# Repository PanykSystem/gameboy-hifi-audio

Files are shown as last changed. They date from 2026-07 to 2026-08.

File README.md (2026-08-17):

# GameBoy HiFi Audio

A Bluetooth audio upgrade for the Game Boy Advance. It removes the console's
stock audio amp and replaces the whole audio back end with an ESP32 and an
ES8388 codec. The mod streams game audio to Bluetooth headphones and speakers,
and it also drives the GBA's built-in speaker and wired headphone jack itself,
with onboard EQ, volume, and sound effects.

<p align="center">
  <a href="https://youtu.be/aRh9ZIPrqOQ">
    Watch: I Fixed the GBA's Audio
  </a>
  <br>
  <sub>What the mod does, start to finish</sub>
</p>

<p align="center">
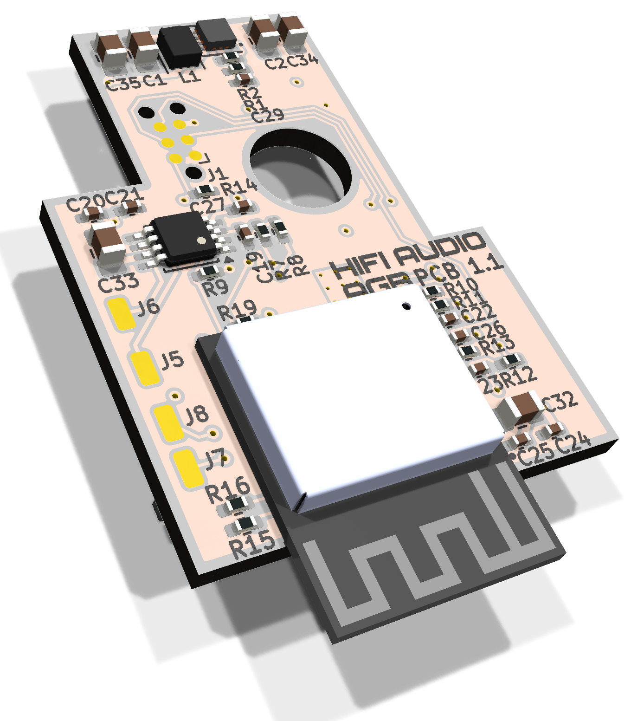
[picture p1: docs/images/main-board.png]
GameBoy HiFi AGB main board
  
  &nbsp;&nbsp;
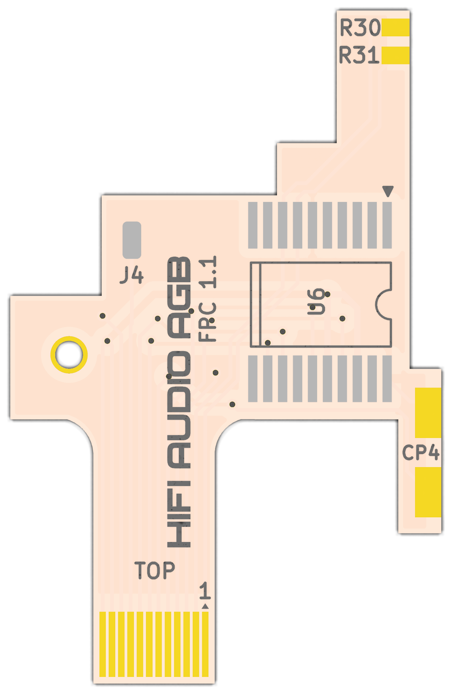
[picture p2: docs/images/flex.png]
GameBoy HiFi AGB flex
  
  <br>
  <sub>AGB main board (left) and flex (right)</sub>
</p>

What you get:

- Bluetooth (A2DP) output to any standard headphones or speaker.
- Wired headphones and the internal speaker, driven by the onboard codec.
- EQ, volume, and sound-effect cues, tunable from a phone or laptop over
  Bluetooth (no app install, it runs in the browser).
- A battery-saver mode that puts the radio and CPU to sleep and passes audio
  through the codec in analog, for long unplugged sessions.
- Firmware updates over Bluetooth.

<p align="center">
  The web config page: live spectrum and equalizer, tuned in the browser over Bluetooth
  <br>
  <sub>The browser config page: a live spectrum and per-output EQ, tuned over Bluetooth with no app to install</sub>
</p>

Prebuilt, pre-assembled kits are coming soon at
[cajunpanda.com](https://cajunpanda.com/shop/gameboy-hifi-audio), for anyone who would
rather not source the parts and solder it themselves. Kits ship pre-flashed and update
over Bluetooth, so they need no programming cable. The listing also has an A/B recording
of the mod with its filters off and on, and an optional speaker.

Questions, build photos, and troubleshooting happen on the
[Discord](https://discord.gg/6BNetnK6kC).

This repository currently holds the board for the original Game Boy Advance
(AGB). The firmware is shared across models. Boards for other Game Boy models
will be added under `hardware/` as they are designed.

## Pick your path

This project has three kinds of reader. Start with the doc that matches you.

- **You have a GameBoy HiFi board, or one already in your GBA.**
  [docs/AGB-INSTALL.md](docs/AGB-INSTALL.md) fits the board into a Game Boy Advance, and
  [docs/MANUAL.md](docs/MANUAL.md) covers using it: pairing, the control button,
  the modes, the web config page, and troubleshooting.

- **You want to build the boards yourself.**
  Read [docs/HARDWARE.md](docs/HARDWARE.md): the bill of materials, the KiCad
  boards, fabrication, and assembly. It links on to the install guide once the
  boards are ready.

- **You want to change the firmware.**
  Read [docs/FIRMWARE.md](docs/FIRMWARE.md): the toolchain, build and flash,
  the architecture, the config options, and how the control surfaces work.

## Repository layout

```
firmware/        ESP-IDF firmware (PlatformIO project), shared across boards
hardware/agb/    KiCad projects for the AGB main board and flex (schematic carries the BOM)
web/             Web Bluetooth config page (hosted on GitHub Pages)
tools/           make_clip.py (clip authoring), bringup.py (bench current<->boot correlation)
docs/            the guides above
```

## License

- Firmware and other source code: MIT, see [LICENSE](LICENSE).
- Hardware (schematics, board layouts, footprints): CERN-OHL-P v2, see
  [hardware/LICENSE](hardware/LICENSE).
- Documentation: CC BY 4.0, see [docs/LICENSE](docs/LICENSE).

You can build, modify, sell, and redistribute all of it, including in your own
products, as long as you keep the attribution and the license notices.

## A note on the trademark

Game Boy and Game Boy Advance are trademarks of Nintendo. This is an
independent, unofficial project and is not affiliated with or endorsed by
Nintendo.

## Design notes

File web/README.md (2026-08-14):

# Web config page

A single-file Web Bluetooth control panel for the mod's BLE config server
(`firmware/src/ble_config.c`). It tunes the DSP settings (speaker and Bluetooth
volume, EQ, sound effects), sets the R-button hold timings, plays chimes and
clips, saves to the device, and updates the firmware over the air. It also
converts a dropped audio file to a startup clip in the browser and uploads it.
No app, no WiFi, just Chrome or Edge talking to the ESP32 over Bluetooth.

## Hosting (GitHub Pages)

`.github/workflows/pages.yml` deploys this folder to GitHub Pages on every push
to `main` that touches `web/`. One-time setup: repo Settings, Pages, Source =
GitHub Actions. The page is then served at `https://<user>.github.io/<repo>/`.

Web Bluetooth needs a secure context, which the Pages HTTPS provides. For local
work, serve over localhost (for example `python3 -m http.server` in this folder).
Opening the file directly does not expose `navigator.bluetooth`.

## Use

1. Power the mod. The BLE server advertises as "GameBoy HiFi Setup" with slow
   advertising to keep current low, so discovery can take a couple of seconds.
2. Open the page, click Connect, and pick "GameBoy HiFi Setup".
3. The controls fill in from the device and push live edits back. Save to device
   persists them. Changes made from the UART console show up here through
   notifications.

On Linux, Chrome needs the experimental web platform features flag.

## Firmware update

The Firmware update card pushes a new `firmware.bin` to the device over
Bluetooth. Drop the file, click Flash firmware, and keep the page open until the
device reboots into the new image (a minute or two; audio pauses). The transfer
uses windowed flow control with a host-side crc32 and on-device SHA-256
validation before the boot slot swaps. The dropped file is checked before any of
it is sent: it has to be an ESP32 app image, built from this project, and small
enough for the app slot, so the cable-only full-flash image or another product's
firmware is refused in the picker instead of partway through a transfer. The
device enforces the same project check itself when the transfer ends. Older firmware without the OTA
characteristics is detected, and the card disables itself.

The card shows the installed firmware version and slot from the device. The
version comes from `CONFIG_APP_PROJECT_VER` in `firmware/sdkconfig.defaults`.

## Wire format

The settings characteristic is a packed little-endian blob mirroring
`gbhifi_settings_t`. The exact layout is documented in both `web/index.html` and
`firmware/src/ble_config.c` (`SETTINGS_WIRE_LEN`); keep the two in lockstep. The
mode field is read-only status: entering Battery saver duty-cycles the radio to
sleep, so the page cannot reverse it. The R-button hold gesture owns the mode.

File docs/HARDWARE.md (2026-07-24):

# GameBoy HiFi Audio: Hardware Guide

This guide is for building the mod yourself: ordering the boards, sourcing
parts, assembling, and installing it in a Game Boy Advance. The KiCad projects
under `hardware/agb/` are the authoritative reference for the schematic, the
board layout, and the exact net and pin assignments. This document is the
overview.

This is an advanced modification. It requires removing a surface-mount chip from
the GBA mainboard, fine-pitch soldering, and reflow or hot-air work on a QFN
part. If you are not comfortable with that, have it done by someone who is.

## What is on the boards

There are two boards for the AGB:

- **Main board** (`hardware/agb/agb-hifi-audio-pcb`): the ESP32 module, the
  audio codec, the power supply, and the speaker amplifier.
- **Flex** (`hardware/agb/agb-hifi-audio-fpc`): a flexible circuit that solders
  to the GBA's audio-amp footprint and carries power, ground, the audio taps,
  and the control-button signal back to the main board. It folds over once
  during installation.

<p align="center">
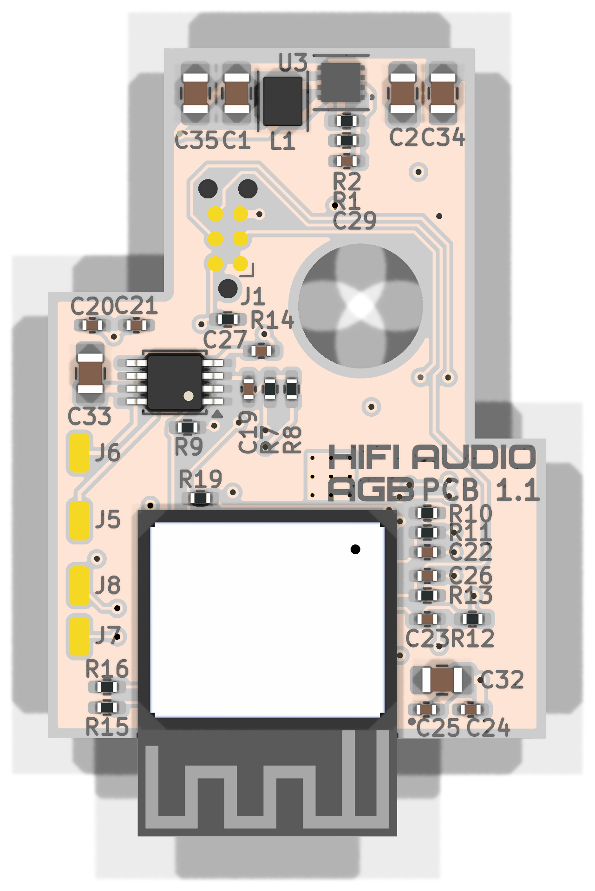
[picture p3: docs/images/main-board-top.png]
AGB main board, top
  
  &nbsp;&nbsp;
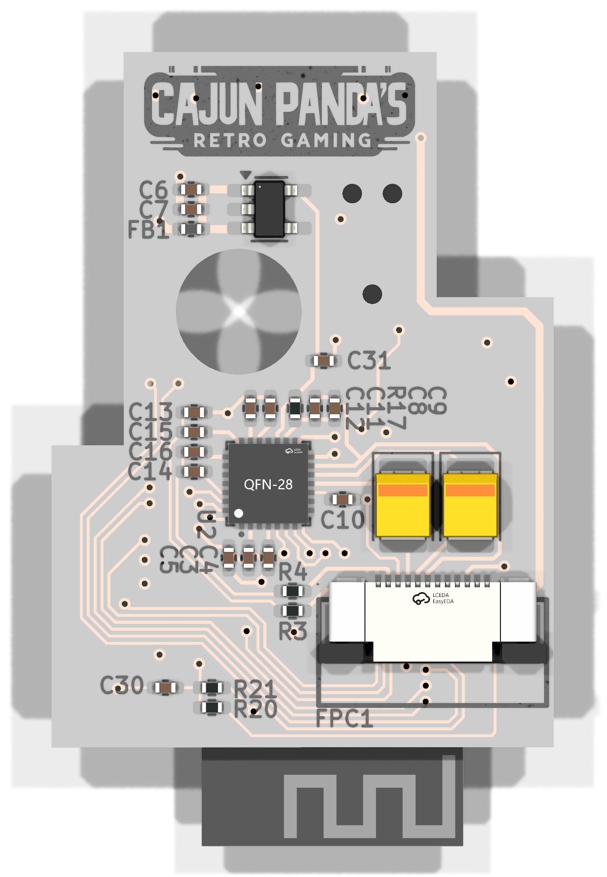
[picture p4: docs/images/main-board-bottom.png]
AGB main board, bottom
  
  <br>
  <sub>Main board, top (left) and bottom (right)</sub>
</p>

## Key parts

The bill of materials lives in the KiCad schematic itself (the source of truth),
where each symbol carries its manufacturer, LCSC, and DigiKey part numbers. Export
it from the [main-board schematic](../hardware/agb/agb-hifi-audio-pcb/). The main
active parts are:

| Ref  | Part | Function |
| ---- | --- | --- |
| U1 | ESP32-PICO-MINI-02-N8R2 | MCU, Bluetooth radio, 8 MB flash |
| U2 | ES8388 | Stereo audio codec: ADC, DAC, headphone amp, analog bypass |
| U3 | TPS61021A | Boost converter, battery to 3.3 V |
| U4 | PAM8302A | Mono Class-D amplifier for the internal speaker |
| U5 | LP5907MFX-3.0 | Low-noise LDO for the codec's analog supply |
| FPC1 | AFC07-S12ECA-00 | 12-pin flat-flex connector for the flex |

The ES8388 is a QFN-28 and is not hand-solderable in the usual sense. Plan on a
stencil and reflow, or hot air. The ESP32 module needs the same treatment: its
pads sit under the module's edge rather than as exposed castellations, so an iron
cannot reach them all. Its pitch is coarser than the codec's, so it is the more
forgiving of the two, but it is still a reflow or hot-air part.

FPC1 is a JLCPCB-stocked part (LCSC C262585). It replaced the Hirose
FH12A-12S-0.5SH, which mates the same flex but uses a different fitting-nail
land pattern, so the Hirose only fits board revisions before 1.1.

### Full bill of materials

Passives are listed by value; the schematic carries the exact manufacturer,
LCSC, and DigiKey part numbers for every line. 26 lines, 60 pieces.

| Ref(s) | Qty | Value / part | Package |
| --- | --- | --- | --- |
| C1, C2, C32–C35 | 6 | 22 µF 25 V | 0805 |
| C3, C6, C8, C10, C11, C20, C24 | 7 | 10 µF | 0402 |
| C4, C7, C9, C21, C25, C26, C30 | 7 | 100 nF | 0402 |
| C5, C15, C16, C19, C27, C31 | 6 | 1 µF | 0402 |
| C12 | 1 | 4.7 µF | 0402 |
| C13, C14 | 2 | 10 nF C0G | 0402 |
| C17, C18 | 2 | 220 µF 6.3 V (tantalum) | EIA-3528 |
| C22, C23 | 2 | 10 nF | 0402 |
| C29 | 1 | 10 pF | 0402 |
| R1 | 1 | 316 kΩ | 0402 |
| R2, R9, R20, R21 | 4 | 100 kΩ | 0402 |
| R3, R4 | 2 | 2.2 kΩ | 0402 |
| R7, R8 | 2 | 15 kΩ | 0402 |
| R10, R13, R14 | 3 | 10 kΩ | 0402 |
| R11, R12 | 2 | 1 kΩ | 0402 |
| R15, R16 | 2 | 4.7 kΩ | 0402 |
| R17 | 1 | 10 Ω | 0402 |
| R19 | 1 | 33 Ω | 0402 |
| L1 | 1 | 0.47 µH (power inductor) | 2.5 × 2.0 mm |
| FB1 | 1 | 600 Ω @ 100 MHz (ferrite bead) | 0402 |
| FPC1 | 1 | AFC07-S12ECA-00 | 12-pin FFC |
| U1 | 1 | ESP32-PICO-MINI-02-N8R2 | SMD module |
| U2 | 1 | ES8388 | QFN-28 (4 × 4 mm) |
| U3 | 1 | TPS61021A | WSON-8 (2 × 2 mm) |
| U4 | 1 | PAM8302A | MSOP-8 |
| U5 | 1 | LP5907MFX-3.0 | SOT-23-5 |

## Ordering the boards

Open the KiCad project (KiCad 10 or newer) and export fabrication data:

1. Run the design rule check and the electrical rule check first.
2. Plot Gerbers and drill files for the main board, and again for the flex.
3. Export the position (centroid) file if you are using an assembly service.

The flex needs special fabrication settings: it is a two-layer polyimide flex
with a stiffener under the connector fingers, and a few intentional edge-plated
lands. Those requirements are written into the flex board as fabrication notes
on the documentation layer, so they travel with the Gerbers. Read them before
you order, and tell the fab house it is a flex, not a rigid board.

JLCPCB and PCBWay both make these. For the main board, their assembly services
can place most of the parts, which saves you the QFN reflow. The JLCPCB order-form
settings used for these boards (flex material, ENIG, coverlay, stiffener, and the
rest) are recorded in [JLCPCB-FAB-ORDER.md](JLCPCB-FAB-ORDER.md) so reorders stay
consistent.

## Power

The GBA's switched battery rail (about 2.4 V to 3.2 V) feeds the TPS61021A
boost converter, which produces 3.3 V for the ESP32, the codec's digital side,
and the speaker amp.

The codec's analog supply (AVDD, and HPVDD behind R17) is its own domain: the
3.3 V rail passes through the ferrite (FB1) into U5, an LP5907MFX-3.0 low-noise
LDO (~82 dB PSRR at 1 kHz), which regulates a quiet 3.0 V for the codec's analog
stages. It isolates the codec's DAC, mixer, and headphone amp from the boost
rail, which the Bluetooth radio's wake-up bursts modulate. Bulk caps are spread
across the rail (boost output, boost input, ESP32, speaker amp) for brown-out
margin at low battery.

## The audio source

The GBA CPU does not output a line-level analog signal. Its sound pins (S01 and
S02) are a PWM bitstream. The reconstruction that turned that into analog used
to live inside the amp chip you are removing, so the mod includes its own
reconstruction low-pass filter at the tap. The filtered signal feeds the codec's
line inputs. The codec's input range suits this signal directly, so there is no
preamp.

## Installing the mod

Once the boards are assembled, see [AGB-INSTALL.md](AGB-INSTALL.md) to fit the mod into
a Game Boy Advance: removing the stock parts, attaching the flex, wiring the
speaker, and the first firmware flash.

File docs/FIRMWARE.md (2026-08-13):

# GameBoy HiFi Audio: Firmware Guide

This guide is for building, flashing, and modifying the firmware. The firmware
is shared across all board models.

## Toolchain

The firmware is an ESP-IDF project built through PlatformIO, not through
`idf.py`. You need:

- PlatformIO (the `pio` CLI, or the VS Code extension).
- A Tag-Connect TC2030 serial cable for the first cabled flash. The
  [TC2030-NL-FTDI-C232HD](https://www.tag-connect.com/product/tc2030-nl-ftdi-c232hd-ddhsp-0-dtr-usb-to-tc2030-no-legs-serial-cable)
  carries DTR for auto-reset into the bootloader. Later updates go over Bluetooth.

PlatformIO downloads the ESP-IDF framework and the managed components on the
first build. `firmware/sdkconfig.defaults` is the source of truth for the IDF
configuration; the generated `sdkconfig.prod` is not checked in and is
recreated from the defaults.

## Build, flash, monitor

All firmware commands run from inside `firmware/`:

```sh
cd firmware
pio run                          # build
pio run -t upload                # flash over serial
pio run -t upload -t monitor     # flash and open the serial monitor
pio run -t menuconfig            # IDF menuconfig (edits the generated sdkconfig)
pio device monitor               # serial monitor only (115200 8N1)
```

The build output is `.pio/build/prod/firmware.bin`.

### Recommended: benchmux for iterating

For a build-flash-watch loop, [benchmux](https://github.com/cajunpanda/benchmux) is more
convenient than the raw `pio` commands. It owns the serial port and tees output to a shared
logfile, so it flashes without stopping the monitor, the boot log for the new firmware
streams straight into the log you are already watching, and you can follow that log from any
terminal. It also flashes over BLE. Install it per its README, then from `firmware/`:

```sh
serial_proxy.py monitor --port FTDI &    # own the port, stream to /tmp/serial_proxy.log
serial_proxy.py tail                     # follow the log (from any terminal)
serial_proxy.py flash --env prod         # build + upload without stopping the monitor
serial_proxy.py flash --env prod --fs    # also flash the LittleFS clip image
serial_proxy.py send get                 # inject a console command through the monitor
```

`--fs` flashes the LittleFS clip image that a plain upload skips (see "Partitions and the
clip image"), so a `firmware/data/` change needs no separate esptool step. The commands run
once and exit with a status code, which also makes benchmux a good fit for driving the board
from an editor task or an AI coding agent.

If you change `sdkconfig.defaults`, delete `sdkconfig.prod` to force it to
regenerate. Adding a new `CONFIG_*` symbol in `Kconfig.projbuild` also needs
that delete plus a rebuild, otherwise the build reports the symbol as
undeclared.

`pio run -t upload` flashes only the app. It does not write the LittleFS clip
image, so a change under `firmware/data/` needs a separate filesystem flash (see
"Partitions and the clip image" below).

## Configuration

Project options live in `firmware/src/Kconfig.projbuild` under the
"GameBoy HiFi Audio" menu. Reach them with `pio run -t menuconfig`. The groups:

- **Timeouts and timing**: standby and reconnect timing, the silence detector,
  the R-button hold thresholds, debounce, pairing and wake-hold times, and the
  factory-reset hold.
- **BLE GATT config server**: enables the Web Bluetooth control surface.
- **Speaker DSP defaults**: first-boot seed values for volume, the three EQ
  profiles (speaker, headphone, Bluetooth), and the sound cues. These are only
  the initial seeds; live values persist in NVS and are tuned at runtime.
- **Operating modes**: the default mode at boot, and what happens on a wired
  headphone unplug while in Battery saver.
- Two debug toggles: per-second ADC peak logging, and a one-shot waveform dump
  over UART.

## Partitions and the clip image

`firmware/partitions.csv` defines an 8 MB layout with two OTA app slots (so the
firmware can update itself over Bluetooth), an NVS area for settings and
Bluetooth bonds, and a LittleFS `storage` partition for sound clips.

`pio run -t upload` flashes only the app. It does not flash the LittleFS clip
image, so a plain flash leaves whatever clips were already on the board. The
build bakes `firmware/data/` into a `storage.bin` image (the `src/CMakeLists.txt`
`littlefs_create_partition_image(... FLASH_IN_PROJECT)` line owns the exact
fs-size / block-size / name-max the firmware mounts with). To (re)load the clips,
build and write that image to the `storage` partition offset:

```sh
pio run                                              # bakes .pio/build/prod/storage.bin
esptool.py write_flash 0x420000 .pio/build/prod/storage.bin
```

The `storage` offset (`0x420000`) comes from `partitions.csv`; the generated
`flasher_args.json` lists it too.

The first flash on a fresh board must be a full cabled flash: bootloader,
partition table, app into the first slot, an erased otadata, and the clip image.
After that, updates can go over Bluetooth.

The clips themselves are in the GSFX format. Use `tools/make_clip.py` to author
them: `from-wav` converts a 16-bit WAV to a clip (downmix + optional resample),
or `gen-startup` generates a synth test cue.

The boot chime plays over a muted passthrough (see "Init order"). Which clip it
uses comes from the `startup_mode` setting, whose values are `startup_mode_t` in
`settings.h`:

| mode | clip | notes |
| --- | --- | --- |
| `STARTUP_MODERN` | `startup-modern.gsfx` | the Switch/NSO version, the default |
| `STARTUP_ORIGINAL` | `startup-original.gsfx` | the full original GBA chime |
| `STARTUP_CUSTOM` | `startup-custom.gsfx` | ships with a default; replaced by a web-UI upload |
| `STARTUP_OFF` | none | no clip; the live GBA chime plays through |

`STARTUP_OFF` is not `STARTUP_ORIGINAL`. The codec and amp are still coming up
during the GBA's first ~0.9 s, so the passthrough chime is truncated. That is why
the mod voices its own clip.

All three clips ship in the filesystem image. To change one, author a new
`firmware/data/startup-*.gsfx` and reflash the image (see "Partitions and the
clip image").

The web config page can also replace `startup-custom.gsfx` over BLE. It converts
a dropped audio file to GSFX in the browser, then streams it over the same
OTACTL/OTADATA characteristics a firmware update uses (opcodes `CLIP_BEGIN` /
`CLIP_END`). The device writes to a temp file and renames it into place only once
size, CRC32 and the GSFX header check out, so a dropped link leaves the previous
clip intact. A filesystem reflash restores the bundled default.

## Source layout

```
firmware/src/
  main.c            app_main and the boot/init order
  pinmap.h          every PIN_* macro (the single source of truth for GPIOs)
  es8388.{h,c}      codec driver over I2C: power-up, mode, routing, volume
  i2s_codec.{h,c}   full-duplex I2S master to the codec (MCLK from the ESP32)
  audio_pipeline.{h,c}  ADC capture, int16 conversion, DSP, BT stream, DAC fan-out
  dsp.{h,c}         EQ, volume, and cue mixing for the speaker and BT paths
  settings.{h,c}    runtime-tunable parameters, NVS-backed, the control seam
  sfx.{h,c}         cue player: synth cues and clips streamed from LittleFS
  fs.{h,c}          LittleFS mount for the clip store
  console.{h,c}     UART REPL control surface
  ble_config.{h,c}  BLE GATT config server (drives the web page)
  bt_a2d.{h,c}      Bluedroid wrapper: connect, pair, media, bonds, events
  buttons.{h,c}     debounced ISR for the control button and HP-detect
  harness.{h,c}     install diagnostics for the four signals crossing to the GBA
  app_sm.{h,c}      the state machine, speaker-amp gating, and sleep policy
```

## Architecture

### Audio path

The GBA sound pins (S01/S02) are a PWM bitstream. A reconstruction low-pass
filter on the board turns that into analog, which feeds the codec line inputs.
From there:

```
codec ADC -> ESP32 (I2S RX) -> int16 stereo -> DSP -> split:
  Bluetooth:  stream buffer -> A2DP SBC encoder -> radio
  Local:      codec DAC -> headphone amp (jack) and line out -> speaker amp
```

The pipeline is fixed at 44.1 kHz interleaved stereo, 16-bit. The IDF A2DP
source endpoint hard-codes that SBC format and rejects attempts to change it, so
the sample rate, channel count, and bit depth across the codec, the I2S bus, and
the pipeline all exist to feed that fixed sink. Do not change one without the
others.

### Clocking

The ESP32 is the I2S master. It generates MCLK (from the APLL on GPIO0), BCLK,
and LRCK, and the codec is the slave. One clock domain serves both directions,
so there is no asynchronous resampling.

### Init order

`app_main` is ordered to get **audio out as fast as possible** and to keep the
Bluetooth radio off the Game Boy power-on chime. The mod boots on the GBA's
switched rail, so every power-cycle re-runs this and the chime is the first thing
the user hears.

The sequence: log the wake cause and gate a button wake, boot-mute the speaker
amp, init NVS, bring up the I2S clocks and then the codec over I2C. As soon as the
codec is configured, `app_sm_speaker_early_on()` samples HP-detect and unmutes the
speaker amp (only if no headphones are plugged) — well before the state machine
would otherwise. Then the DSP subsystem comes up: `app_sm_prime_volume()` seeds
the speaker volume from the wheel *before* `dsp_init()` reads it (so a wheel-down
user doesn't get a default-volume blare), and the local EQ profile is seeded from
the sampled HP state. The startup chime is then triggered — `dsp_begin_intro()`
mutes the live passthrough while `sfx_trigger_clip("startup")` plays the mod's own
clean, complete chime (so it isn't doubled with the truncated live GBA chime the
codec misses during boot); this is gated so a future setting can disable it and
let the GBA's own chime through. The audio pipeline and buttons start, and the
pending OTA image is confirmed good.

Only then comes Bluetooth, deliberately last among the heavy loads: `app_main`
waits until `CONFIG_GBHIFI_BT_START_DELAY_MS` after power-on **and** until the
startup chime has fully drained (`sfx_cue_active()`, capped so a wedged cue can't
block BT), parks the speaker amp (`app_sm_amp_radio_quiet()`) across the radio
window, then runs `bt_a2d_init()` (controller + radio) and the BLE config server.
This serialization exists because the radio bring-up is the largest, fastest
current step of the whole boot and on a low battery it can sag the boost rail
below the brownout threshold. Three more pieces of that guard live in firmware:

- `CONFIG_ESP_PHY_RF_CAL_NONE=y` (sdkconfig.defaults) — skips the boot-time
  partial RF calibration TX bursts and runs from NVS-stored cal data. Caveat:
  the first boot after an NVS erase runs a *full* cal (bigger spike), where the
  loop breaker below is the safety net.
- **BR/EDR TX capped at -3 dBm right after controller enable** (bt_a2d.c), so
  inquiry/page bursts never run at the +9 dBm default; the CONNECTED handler
  re-asserts the same level per link.
- **Brownout loop breaker** (main.c): an RTC-noinit magic word is armed around
  the radio bring-up and cleared on success. A boot that starts with reset
  reason BROWNOUT while armed knows the radio killed it: the first strike
  retries after a 2 s settle, two consecutive strikes skip BT for that boot and
  come up LOCAL_ONLY (chime + local audio always play instead of a reboot
  loop). A real power cycle scrambles RTC noinit and re-arms BT. All public
  `bt_a2d_*` calls no-op safely on a BT-skipped boot.

This sequence cold-boots cleanly down to a 2.0 V rail, below any usable 2xAA
level. Finally the factory-reset check, the state machine, and the console start.
The order matters; read the comments in `main.c` before reordering anything.

There is no codec read-back verify pass: the production PCB's series-R + short
MCLK routing keep the I2C config writes clean, so `es8388_init()` alone is enough.

### State machine

`app_sm.c` is the only place that owns device state. Button events, Bluetooth
events, audio silence edges, and timers all fold into one FreeRTOS queue drained
by a single task, so there are no cross-task races on the state. It also owns
the speaker-amp mute policy and the sleep policy.

The audio pipeline and the Bluetooth wrapper are isolated from each other and
from the state machine. They publish events through callbacks, and the state
machine is the only subscriber. Keep that boundary: do not add direct calls
between modules.

### Real-time threading

The real-time audio tasks are pinned to core 1, off the Bluetooth controller
core, or A2DP streaming gets garbled when the controller preempts a shared core.
Tickless idle is off for the same timing reason. There is no per-sample `sinf`
or `expf` in the audio task; the DSP uses lookup tables.

## Settings and control surfaces

`settings.c` is the single source of truth for runtime-tunable parameters
(volumes, the EQ profiles, the cues, the mode preferences, the hold times). It
is thread-safe, NVS-backed, and versioned, with a generation counter so the DSP
recomputes coefficients only when something changes.

Control surfaces only ever call the `settings_*` and `sfx_*` API. They never
touch the audio path. There are two:

- **The UART console** (`console.c`): a REPL for bring-up and tuning.
- **The BLE config server** (`ble_config.c`): the same API exposed over
  Bluetooth for the web page.

### Console commands

```
vol <0-100>          speaker volume
volbt <0-100>        Bluetooth volume
eq on|off [b m t]    speaker EQ
eqhp on|off [b m t]  headphone EQ
eqbt on|off [b m t]  Bluetooth EQ
sfx on|off [level]   cue mixing
chime [name]         play a synth cue
play <name>          play a clip
bt connect|pair      drive BT like the button (page bonds / inquiry-pair)
mode a|b             set operating mode (a = bypass/battery, b = DSP)
unplug stay|b        behavior on HP unplug in Mode A
hold [c p m e]       R-button hold thresholds, ms
wheel on|off         VOL wheel drives volume
diag                 install check: VBAT / VOL / PAIR / HP
ls                   list the clip store
save                 persist settings to NVS
get                  show current settings
```

There are also a few bench helpers (`out1`, `out2`, `outvol`, `codecmode`,
`hp`, `sleep`) for hardware bring-up.

## Install check

Four signals run from the mod board to the Game Boy through `FPC1` and the flex,
and `harness.c` classifies each one. The report goes to the boot log, the `diag`
console command, and the BLE `diag` characteristic that drives the web card.

| Signal | FPC1 pin | Open reads as | Why |
| --- | --- | --- | --- |
| VBAT | 11, 12 | ~280 mV vs 2000-3200 installed | the `R20`/`R21` divider is on-board but the rail it measures is not |
| VOL | 7 | raw ~16 vs a ~330 floor | the wheel is a VBAT-referenced divider, so its wiper cannot reach ground |
| PAIR | 9, then flex `J4` | stuck pressed | no pull-up exists on this net anywhere, so it floats LOW |
| HP | 8 | stuck plugged | `R10` pulls it up on-board, upstream of the connector |

Two consequences worth knowing:

- **PAIR floats.** The AGB CPU's keypad pull-up is what holds it HIGH, reached
  through the hand-soldered wire at flex `J4`. A bare board therefore reads the
  Connect/Pair button as permanently held. The boot-time factory reset is gated
  on the battery rail for exactly this reason: without it, every bench visit
  wiped a repaired unit's bonds.
- **HP cannot be judged alone.** "Headphones plugged" and "sense line open" are
  the same level. The report only calls it open once VBAT says the board is on
  bench power, where headphones are implausible.

An open VOL line is also ignored rather than obeyed, so a floating wire cannot
drag the volume to zero and hold it there.

## Web config page

`web/index.html` is a single static page that talks to the BLE config server
over Web Bluetooth. There is no build step and no backend. It is published to
GitHub Pages by `.github/workflows/pages.yml` on any push that touches `web/`.
Web Bluetooth needs a secure context, which the Pages HTTPS provides. The page
reads and writes the settings, uploads clips, and pushes firmware updates.

The System tab mirrors the UART REPL: it streams the device log and takes the
same console commands (`help`, `get`, `batt`, `nr`, ...), so you can watch and
poke a running board over BLE with no cable.

<p align="center">
  The System tab device console: live log and command input over BLE
  <br>
  <sub>The System tab's device console: the live log and the same commands as the wired console, over Bluetooth.</sub>
</p>

## OTA updates

The firmware can update itself over Bluetooth. The web page pushes a new
`firmware.bin` to the BLE OTA characteristics; the device writes it to the
inactive app slot, verifies it, swaps the boot slot, and reboots. If a fresh
image fails to finish booting, the bootloader rolls back to the previous slot.
The running image confirms itself good only after init completes without a
panic.

## Board targets

The build targets the ESP32-PICO-MINI-02-N8R2 module (8 MB flash) on the
production board. `pinmap.h` holds every GPIO assignment and is the single source
of truth for pins; the flash size and partition table are set in
`sdkconfig.defaults` and `partitions.csv`. There is one PlatformIO env, `prod`,
so the build output is always `.pio/build/prod/firmware.bin`.

To bring the firmware up on a different ESP32 module (for example a dev board on
the bench), add a PlatformIO env and adjust the GPIO values in `pinmap.h`, which
is the only file the pin map lives in.

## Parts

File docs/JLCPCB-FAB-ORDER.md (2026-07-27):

# JLCPCB Fab Order Settings

Recorded JLCPCB order configuration for the GameBoy HiFi boards, so reorders stay
consistent. The gerbers, BOM, and CPL come from the export in
[HARDWARE.md → Ordering the boards](HARDWARE.md#ordering-the-boards); this file
captures the fab-side options you pick in the JLCPCB order form after upload.

Most settings are board-agnostic (material, finish, stackup, coverlay, stiffener)
and carry across revisions. The **dimension** and **gerber file name** change per
revision — update those to match the package you are uploading.

## Flex — agb-hifi-audio-fpc

The flex is the fiddly one: a 2-layer polyimide flex with ENIG gold-finger
contacts, a white coverlay, and a polyimide stiffener under the connector lead.
The values below were captured from an order of this board.

### Board & material

| Setting | Value |
| --- | --- |
| Base Material | Flex |
| Layers | 2 |
| PCB Thickness | 0.11 mm |
| Substrate Type  | 25 µm dielectric thickness |
| Specify Stackup | No |
| Layer Sequence  | (default) |

### Copper & finish

| Setting | Value |
| --- | --- |
| Copper Type | Electro-deposited |
| Outer Copper Weight | 1/3 oz |
| Surface Finish | ENIG (gold thickness 1 U") |
| Gold Fingers | Yes |
| Gold Fingers bevel  | 0.3 mm |

### Coverlay & silkscreen

| Setting | Value |
| --- | --- |
| Coverlay Color | White |
| Coverlay Thickness | PI 12.5 µm / AD 15 µm |
| Silkscreen | Black |
| Silkscreen on Stiffener | No |

### Stiffener

| Setting | Value |
| --- | --- |
| Stiffener | Polyimide |
| Polyimide Thickness | 0.225 mm  |
| PI Stiffener Lift Tab | No |

The design does not call out a stiffener thickness — what it requires is a total
finished thickness of 0.30 ±0.05 mm at the fingers, so the tail seats in the ZIF.
Against a 0.11 mm flex body, JLCPCB's 0.225 mm polyimide lands at 0.335 mm, which
is inside that band. Another fab with a different set of stiffener thicknesses
picks whatever hits the same total. The stiffener area itself is the filled
rectangle on the `JLC_Stiffener_Bottom` layer, at the tip of the connector tail
on the bottom side.

### EMI shielding

| Setting | Value |
| --- | --- |
| EMI Shielding Film | Without |

## Main board — agb-hifi-audio-pcb

4-layer rigid FR-4, assembled (JLCPCB places most parts, saving the QFN reflow).
Settings not yet captured — fill in from the order form when the main board is
next ordered.

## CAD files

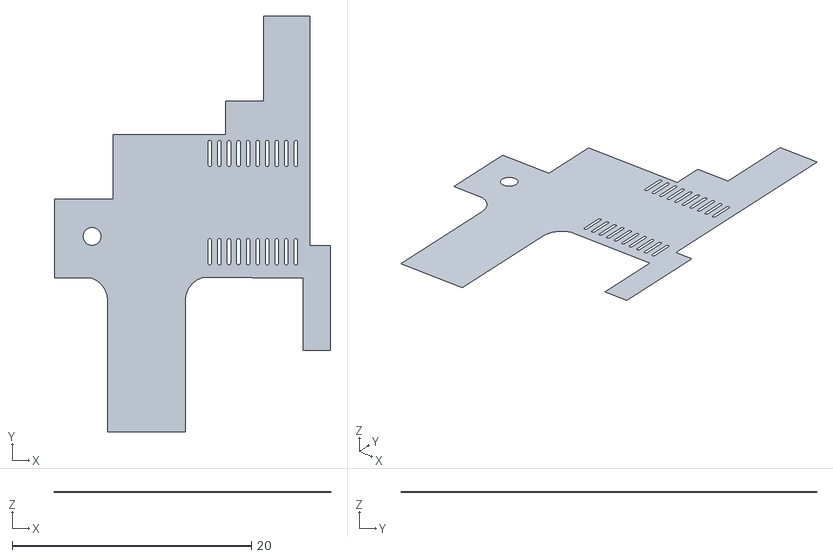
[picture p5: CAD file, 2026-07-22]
hardware/agb/agb-hifi-audio-fpc/agb-hifi-audio-fpc.stl
23.1 x 34.8 x 0.025

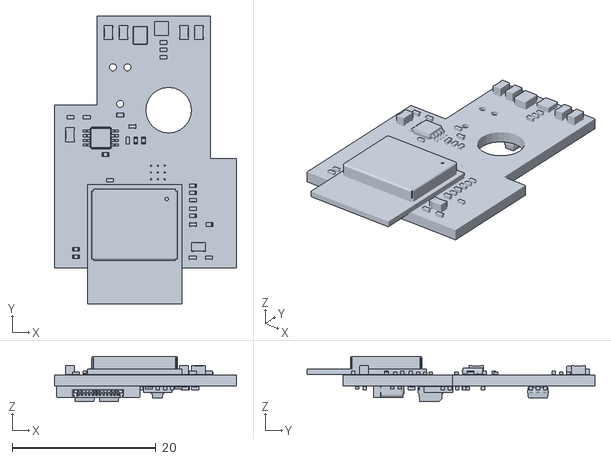
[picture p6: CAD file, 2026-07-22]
hardware/agb/agb-hifi-audio-pcb/agb-hifi-audio-pcb.stl
25.3 x 40.1 x 6.33

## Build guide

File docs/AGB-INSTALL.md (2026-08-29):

# GameBoy HiFi Audio: AGB Installation Guide

This guide covers fitting a GameBoy HiFi board into a Game Boy Advance: removing
the stock parts, soldering on the flex, wiring the speaker, and the first
firmware flash. You need an assembled main board and flex, either from a kit or
built and assembled per [HARDWARE.md](HARDWARE.md).

This is an advanced modification. It involves removing surface-mount parts from
the GBA mainboard and fine-pitch soldering. If you are not comfortable with that,
have it done by someone who is. The changes are permanent: the mod becomes the
console's audio system.

## Video walkthrough

Two videos cover the install, start to finish: the flex install, then the PCB
install and speaker wiring. Watch them before you begin, then follow the written
steps below as you work.

<p align="center">
  <a href="https://youtu.be/mPUGNb_kJ9I">
    Watch: Game Boy Advance HiFi Audio Mod Flex Install
  </a>
</p>

<p align="center">
  <a href="https://youtu.be/ZFsWwqtNinI">
    Watch: Game Boy Advance HiFi Audio Mod PCB Install
  </a>
</p>

## What you need

- An assembled main board and flex.
- A hot-air station (recommended), or a low-melt desoldering alloy such as
  Chipquik, for lifting U6 and CP4 cleanly.
- A fine-tip soldering iron, flux, and fine solder.
- A Tag-Connect TC2030 serial cable for the first flash, only if you assembled
  the board yourself (see First firmware flash below). Prebuilt kits ship
  pre-flashed and need no cable.
- GBA opening tools (a tri-wing driver for the shell).

## Remove the stock parts

Open the GBA and take out the mainboard. Then remove these parts from it:

- U6, the stock audio amplifier.
- CP4, the coupling caps.
- R30 and R31.
- The speaker.

Use hot air to lift U6 and CP4. If you do not have hot air, flood their pins with
a low-melt alloy (Chipquik or similar) and lift them with the iron. Work
carefully: the flex solders back onto these same footprints, so keep the pads
clean and intact. R30, R31, and the speaker come off with a regular iron.

<!-- photo: U6, CP4, R30, R31, and the speaker removed -->

## Solder on the flex

The flex solders to the freed footprints: U6, CP4, R30, R31, and the speaker
pads. That is how the mod picks up power, ground, the audio taps, the headphone
sleeve return, and the R-button net, and it anchors the flex at the speaker
holes.

Solder the flex exactly per its silkscreen and the KiCad flex project. Follow
that pad mapping, not a generic pinout.

### Tapping the CPU audio (two ways)

The two audio signals (the CPU sound pins S0 and S1) can reach the flex by either
route. Pick whichever you find easier; the result is electrically the same.

- **At the R30 / R31 pads (default).** The flex lands solder directly onto the
  R30 and R31 footprints. These are small pads right at the flex edge, so this is
  the fiddliest joint of the whole install.
- **Through the U6 footprint (alternative).** Bridge across each of the R30 and
  R31 footprints with a short length of fine wire, so the audio passes straight
  through to the U6 footprint. The flex then picks S0 and S1 up at the U6 pads
  (where it already solders), and nothing has to land on the tiny R30 / R31 flex
  lands.

If an S0 or S1 pad lifts or is damaged while you remove the stock parts, bridge
from it to the nearby S0 / S1 via instead. It is the same net, so the tap still
works.

<!-- photo: flex soldered onto the footprints -->

## Connect the boards and the speaker

1. Connect the flex to the main board through the flat-flex connector.
2. Reattach the GBA's own speaker — the one you removed from the mainboard — to
   the mod PCB's `J5` / `J6` pads, not back to the GBA mainboard. The mod's
   own amplifier drives it.
3. Fold the flex as designed and secure the main board inside the shell.

<!-- photo: flex connected, speaker wired, board secured -->

## First firmware flash

Prebuilt kits ship pre-flashed. If you bought one, skip this step and update over
Bluetooth from the web config page.

A board you assembled yourself has no firmware. Flash it once through the board's
Tag-Connect serial port, then later updates go over Bluetooth. The recommended
cable is the [Tag-Connect TC2030-NL-FTDI-C232HD](https://www.tag-connect.com/product/tc2030-nl-ftdi-c232hd-ddhsp-0-dtr-usb-to-tc2030-no-legs-serial-cable),
which carries the DTR line so the flasher can reset the board into the bootloader
on its own.

See [FIRMWARE.md](FIRMWARE.md) for the build and flash steps.

## After installation

Reassemble the console and power it on. The mod runs off the GBA's battery rail,
so it starts with the console. See [MANUAL.md](MANUAL.md) for pairing, the
control button, and the operating modes.

## Cautions

- Removing U6 and CP4 is permanent. The mod becomes the GBA's audio system.
- Desolder U6 and CP4 with hot air or a low-melt alloy so you do not lift their
  pads; the flex reuses those footprints.

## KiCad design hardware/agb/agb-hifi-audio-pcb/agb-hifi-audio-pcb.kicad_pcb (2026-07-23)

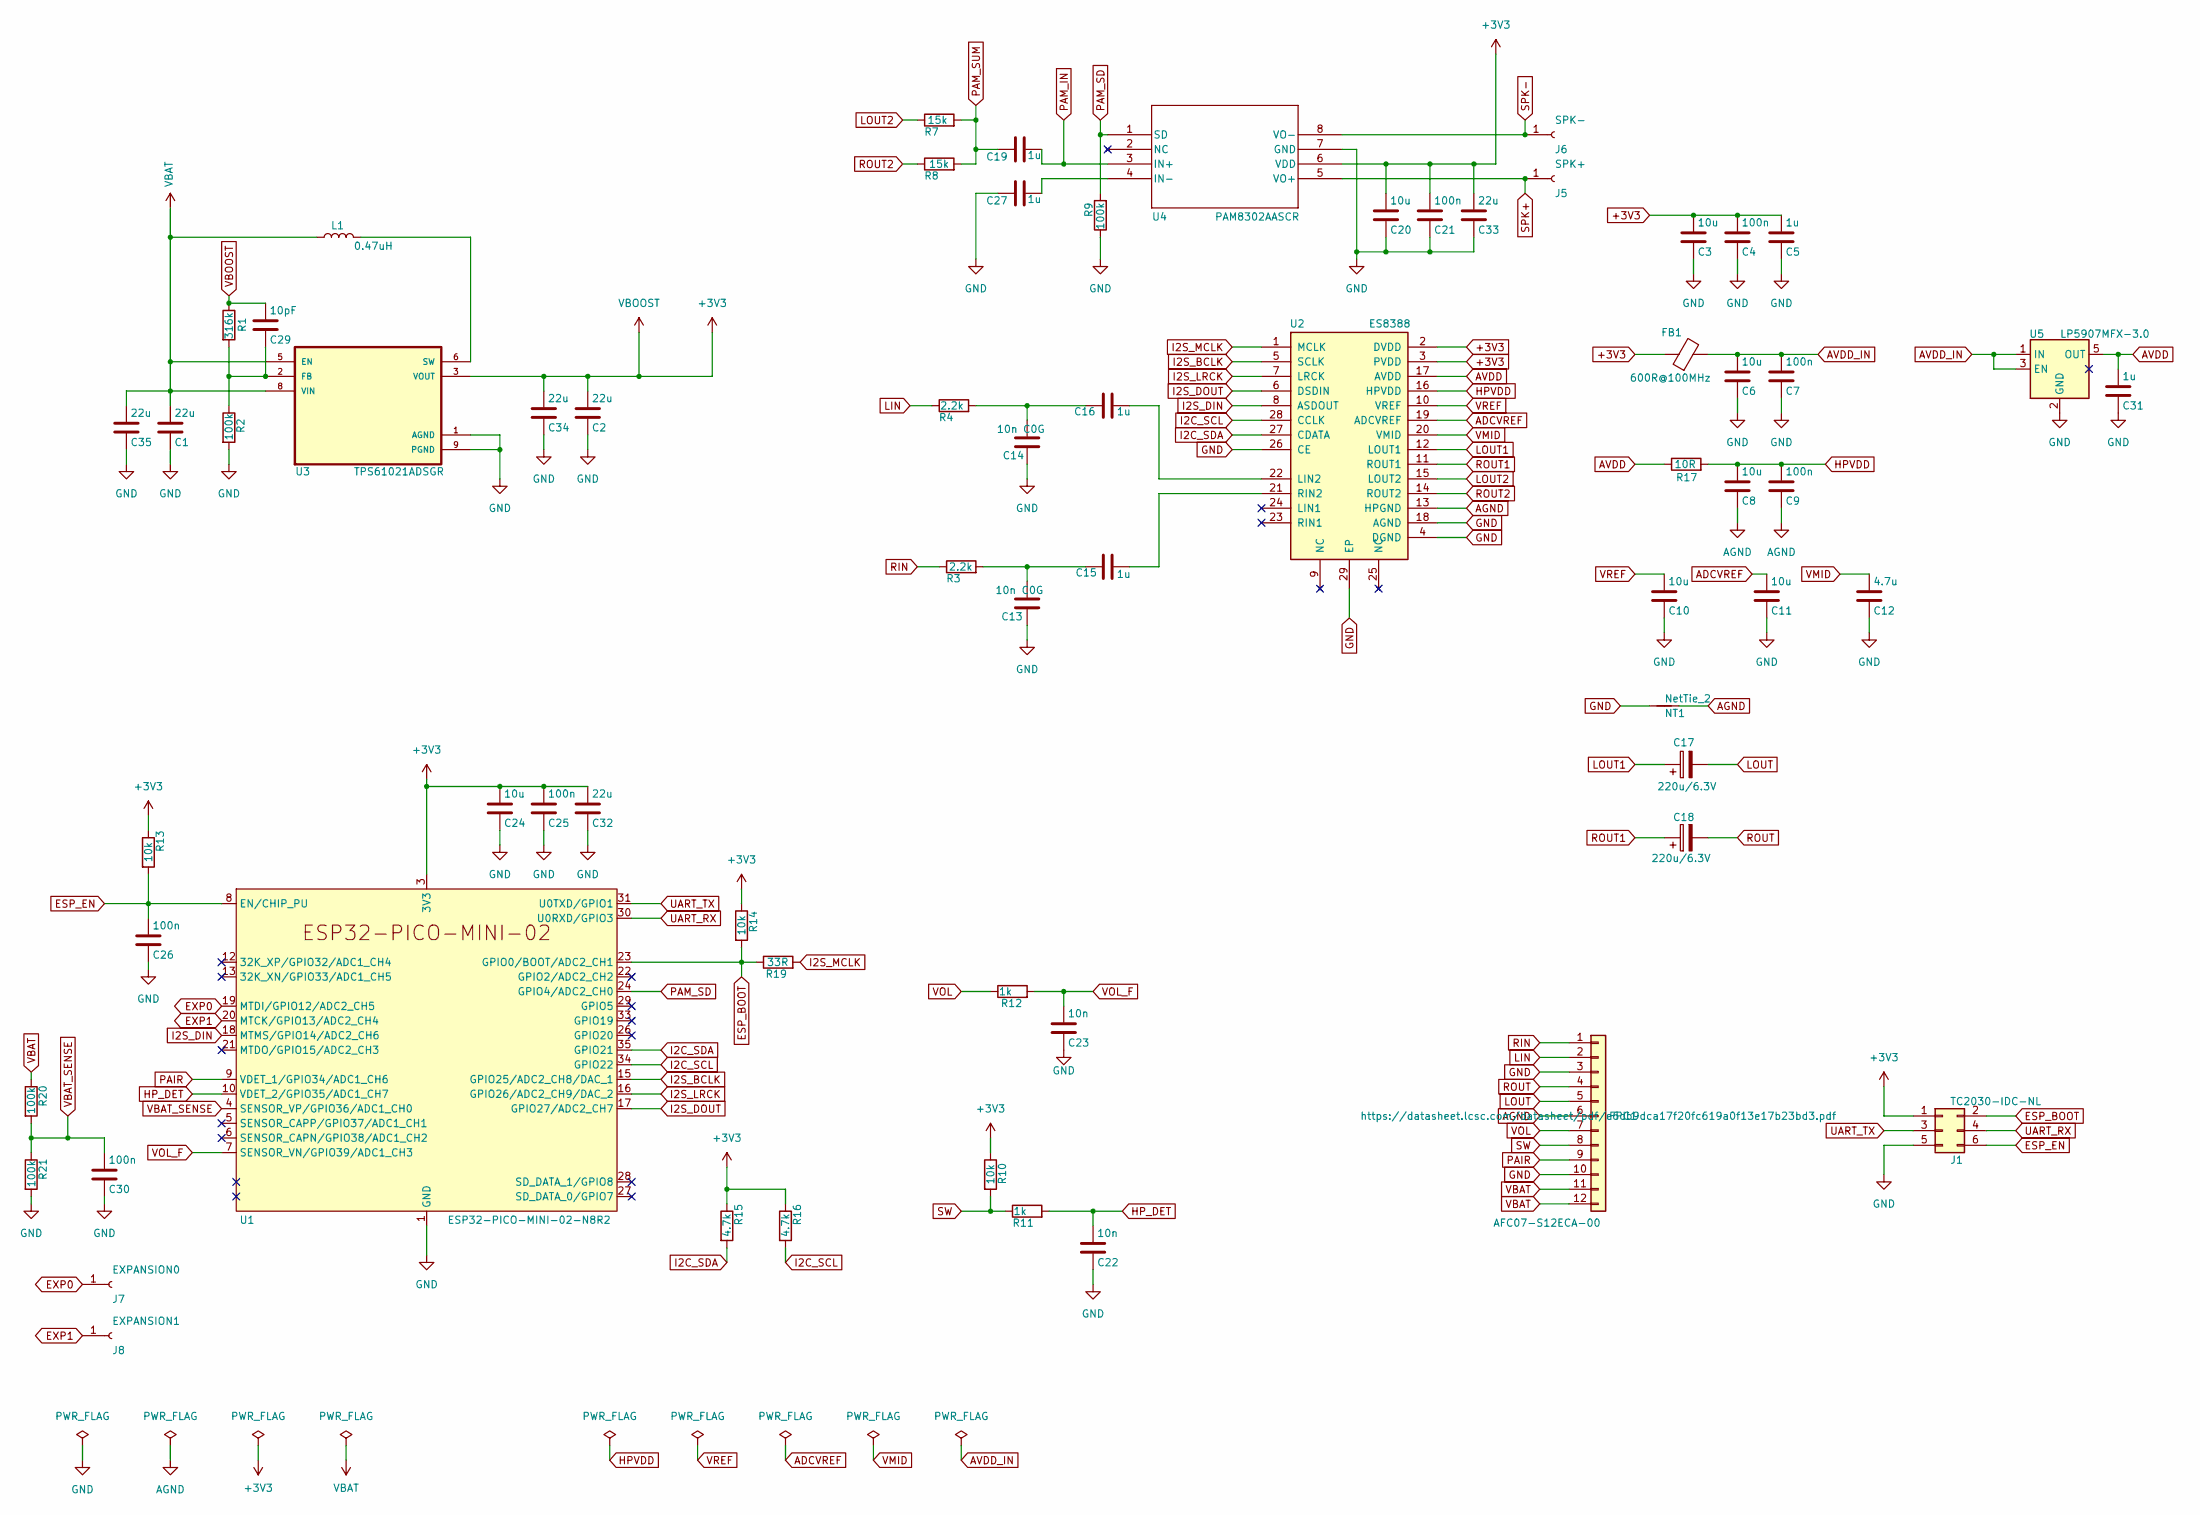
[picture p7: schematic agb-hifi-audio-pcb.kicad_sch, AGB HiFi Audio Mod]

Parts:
C1, C2, C32, C33, C34, C35: 22u; C_0805_2012Metric_Pad1.18x1.45mm_HandSolder; MPN CL21A226MAQNNNE; LCSC C45783
C3, C6, C8, C10, C11, C20, C24: 10u; C_0402_1005Metric_Pad0.74x0.62mm_HandSolder; MPN CL05A106MQ5NUNC; LCSC C15525
C4, C7, C9, C21, C25, C26, C30: 100n; C_0402_1005Metric_Pad0.74x0.62mm_HandSolder; MPN CL05B104KO5NNNC; LCSC C1525
C5, C15, C16, C19, C27, C31: 1u; C_0402_1005Metric_Pad0.74x0.62mm_HandSolder; MPN CL05A105KA5NQNC; LCSC C52923
C12: 4.7u; C_0402_1005Metric_Pad0.74x0.62mm_HandSolder; MPN CL05A475MP5NRNC; LCSC C23733
C13, C14: 10n C0G; C_0402_1005Metric_Pad0.74x0.62mm_HandSolder; MPN GRM1555C1E103JE01D; LCSC C3855387
C17, C18: 220u/6.3V; CP_EIA-3528-21_Kemet-B_HandSolder; MPN T520B227M006ATE045; LCSC C254404
C22, C23: 10n; C_0402_1005Metric_Pad0.74x0.62mm_HandSolder; MPN CL05B103KB5NNNC; LCSC C15195
C29: 10pF; C_0402_1005Metric_Pad0.74x0.62mm_HandSolder; MPN CL05C100JB5NNNC; LCSC C32949
FB1: 600R@100MHz; L_0402_1005Metric_Pad0.77x0.64mm_HandSolder; MPN BLM15AG601SN1D; LCSC C76884
FPC1: AFC07-S12ECA-00; FPC-SMD_12P-P0.50_AFC07-S12ECA-00; MPN AFC07-S12ECA-00; LCSC C262585
J1: TC2030-IDC-NL; Tag-Connect_TC2030-IDC-NL_2x03_P1.27mm_Vertical
J5: SPK+; SolderWirePad_1x01_SMD_1x2mm
J6: SPK-; SolderWirePad_1x01_SMD_1x2mm
J7: EXPANSION0; SolderWirePad_1x01_SMD_1x2mm
J8: EXPANSION1; SolderWirePad_1x01_SMD_1x2mm
L1: 0.47uH; L_Sunlord_SWPA252012S; MPN WIP252012P-R47ML; LCSC C964119
NT1: NetTie_2; NetTie-2_SMD_Pad0.2mm
R1: 316k; R_0402_1005Metric_Pad0.72x0.64mm_HandSolder; MPN 0402WGF3163TCE; LCSC C25777
R2, R9, R20, R21: 100k; R_0402_1005Metric_Pad0.72x0.64mm_HandSolder; MPN 0402WGF1003TCE; LCSC C25741
R3, R4: 2.2k; R_0402_1005Metric_Pad0.72x0.64mm_HandSolder; MPN 0402WGF2201TCE; LCSC C25879
R7, R8: 15k; R_0402_1005Metric_Pad0.72x0.64mm_HandSolder; MPN 0402WGF1502TCE; LCSC C25756
R10, R13, R14: 10k; R_0402_1005Metric_Pad0.72x0.64mm_HandSolder; MPN 0402WGF1002TCE; LCSC C25744
R11, R12: 1k; R_0402_1005Metric_Pad0.72x0.64mm_HandSolder; MPN 0402WGF1001TCE; LCSC C11702
R15, R16: 4.7k; R_0402_1005Metric_Pad0.72x0.64mm_HandSolder; MPN 0402WGF4701TCE; LCSC C25900
R17: 10R; R_0402_1005Metric_Pad0.72x0.64mm_HandSolder; MPN 0402WGF100JTCE; LCSC C25077
R19: 33R; R_0402_1005Metric_Pad0.72x0.64mm_HandSolder; MPN 0402WGF330JTCE; LCSC C25105
U1: ESP32-PICO-MINI-02-N8R2; MODULE_ESP32-PICO-MINI-02; MPN ESP32-PICO-MINI-02-N8R2; LCSC C2980306
U2: ES8388; QFN-28-1EP_4x4mm_P0.45mm_EP2.4x2.4mm_ThermalVias; MPN ES8388; LCSC C365736
U3: TPS61021ADSGR; DSG0008A_TEX; MPN TPS61021ADSGR; LCSC C193037
U4: PAM8302AASCR; MSOP-8_3x3mm_P0.65mm; MPN PAM8302AASCR; LCSC C113367
U5: LP5907MFX-3.0; SOT-23-5_HandSoldering; MPN LP5907MFX-3.0/NOPB; LCSC C475492

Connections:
AVDD: C31.1, R17.1, U2.17 (AVDD), U5.5 (OUT)
ESP_BOOT: J1.2, R14.2, R19.1, U1.23 (GPIO0/BOOT/ADC2_CH1)
ESP_EN: C26.1, J1.6, R13.2, U1.8 (EN/CHIP_PU)
EXP0: J7.1 (Pin_1_1), U1.19 (MTDI/GPIO12/ADC2_CH5)
EXP1: J8.1 (Pin_1_1), U1.20 (MTCK/GPIO13/ADC2_CH4)
HP_DET: C22.1, R11.2, U1.10 (VDET_2/GPIO35/ADC1_CH7)
I2C_SCL: R16.2, U1.34 (GPIO22), U2.28 (CCLK)
I2C_SDA: R15.2, U1.35 (GPIO21), U2.27 (CDATA)
I2S_BCLK: U1.15 (GPIO25/ADC2_CH8/DAC_1), U2.5 (SCLK)
I2S_DIN: U1.18 (MTMS/GPIO14/ADC2_CH6), U2.8 (ASDOUT)
I2S_DOUT: U1.17 (GPIO27/ADC2_CH7), U2.6 (DSDIN)
I2S_LRCK: U1.16 (GPIO26/ADC2_CH9/DAC_2), U2.7 (LRCK)
I2S_MCLK: R19.2, U2.1 (MCLK)
LIN: FPC1.2, R4.1
LOUT: C17.2, FPC1.5
LOUT1: C17.1, U2.12 (LOUT1)
LOUT2: R7.1, U2.15 (LOUT2)
unnamed: C13.1, C15.1, R3.2
unnamed: C14.1, C16.1, R4.2
unnamed: L1.2, U3.6 (SW), U3.7 (SW)
unnamed: C16.2, U2.22 (LIN2)
unnamed: C15.2, U2.21 (RIN2)
unnamed: C29.2, R1.2, R2.1, U3.2 (FB)
unnamed: C27.2, U4.4 (IN-)
PAIR: FPC1.9, U1.9 (VDET_1/GPIO34/ADC1_CH6)
PAM_IN: C19.2, U4.3 (IN+)
PAM_SD: R9.2, U1.24 (GPIO4/ADC2_CH0), U4.1 (SD)
PAM_SUM: C19.1, R7.2, R8.2
RIN: FPC1.1, R3.1
ROUT: C18.2, FPC1.4
ROUT1: C18.1, U2.11 (ROUT1)
ROUT2: R8.1, U2.14 (ROUT2)
SPK+: J5.1 (Pin_1_1), U4.5 (VO+)
SPK-: J6.1 (Pin_1_1), U4.8 (VO-)
SW: FPC1.8, R10.2, R11.1
UART_RX: J1.4, U1.30 (U0RXD/GPIO3)
UART_TX: J1.3, U1.31 (U0TXD/GPIO1)
VBAT_SENSE: C30.1, R20.2, R21.1, U1.4 (SENSOR_VP/GPIO36/ADC1_CH0)
VOL: FPC1.7, R12.1
VOL_F: C23.1, R12.2, U1.7 (SENSOR_VN/GPIO39/ADC1_CH3)

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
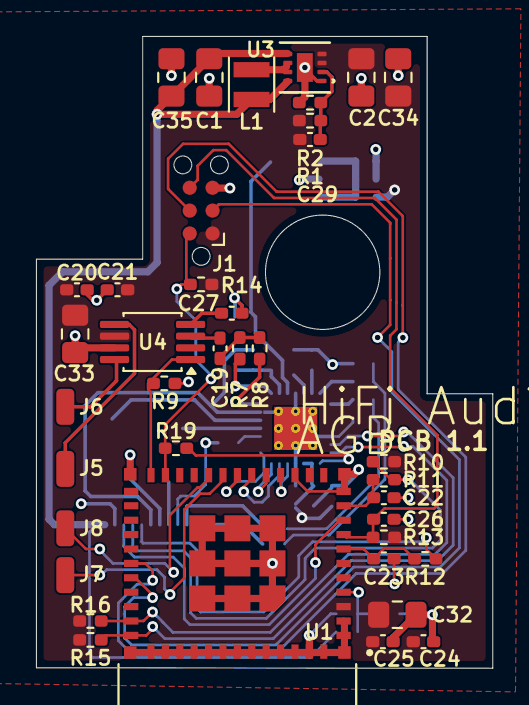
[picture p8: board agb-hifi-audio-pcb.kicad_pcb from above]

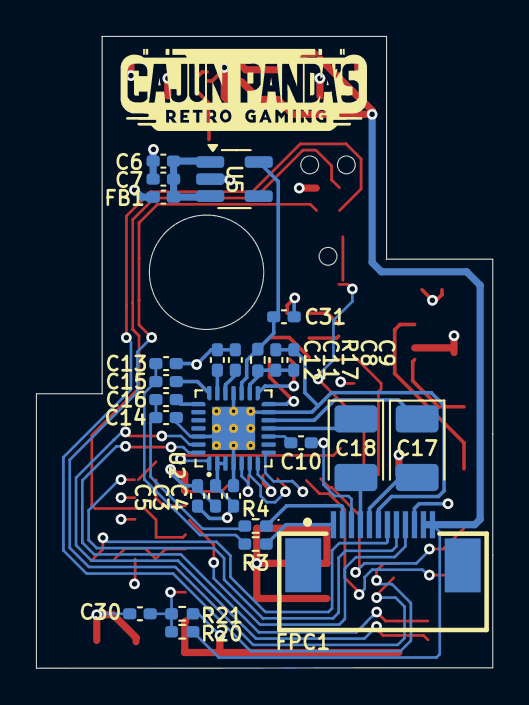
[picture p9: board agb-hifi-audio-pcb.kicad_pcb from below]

Board: 4 copper layers, 25.3 x 35.1 mm, 66 parts (28 on the bottom side), 49 nets.

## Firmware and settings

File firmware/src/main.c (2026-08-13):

#include <inttypes.h>

#include "freertos/FreeRTOS.h"
#include "freertos/task.h"
#include "esp_attr.h"
#include "driver/gpio.h"
#include "driver/rtc_io.h"
#include "esp_app_desc.h"
#include "esp_err.h"
#include "esp_log.h"
#include "esp_ota_ops.h"
#include "esp_sleep.h"
#include "esp_timer.h"
#include "esp_system.h"
#include "nvs_flash.h"

#include "sdkconfig.h"

#include "app_sm.h"
#include "audio_pipeline.h"
#include "ble_config.h"
#include "bt_a2d.h"
#include "buttons.h"
#include "console.h"
#include "dsp.h"
#include "es8388.h"
#include "fs.h"
#include "harness.h"
#include "i2s_codec.h"
#include "pinmap.h"
#include "settings.h"
#include "sfx.h"

static const char *TAG = "gbhifi";

// ---- BT brownout loop breaker ----------------------------------------------
// Enabling the BT controller powers up the RF PHY and runs its calibration -- a
// fast current spike the boost converter must ride through. On a low battery
// (VIN near 2.4 V) the rail can dip below the brownout threshold, and because
// the BOD fires at the same point every boot, the board loops forever. Arm a
// magic word in RTC noinit RAM just before the radio comes up and clear it once
// BT init returns: if a boot then starts with reset reason BROWNOUT while the
// word is armed, the radio is what killed us. First such boot retries with an
// extra settle; after BT_BOD_MAX_TRIES consecutive kills the boot skips BT
// entirely, so the user gets chime + local audio instead of a reboot loop. RTC
// noinit survives the BOD's software reset but scrambles on a real power-off,
// so a battery change / power cycle re-arms BT automatically.
#define BT_BOD_MAGIC      0x42D0B000u   // upper 24 bits magic, low 8 = attempt count
#define BT_BOD_MAGIC_MASK 0xFFFFFF00u
#define BT_BOD_MAX_TRIES  2
static RTC_NOINIT_ATTR uint32_t s_bt_bod_guard;

// How many consecutive boots the BT controller enable has brownout-reset us,
// or 0 on a healthy boot. Reads the guard the *previous* boot armed, then
// clears it, so a brownout anywhere OUTSIDE the armed radio window (e.g. mid
// chime on a truly dead battery) isn't mis-attributed to the radio next boot.
// Call once, early in app_main.
static uint32_t bt_bod_kills(void)
{
    uint32_t kills = 0;
    if (esp_reset_reason() == ESP_RST_BROWNOUT &&
        (s_bt_bod_guard & BT_BOD_MAGIC_MASK) == BT_BOD_MAGIC) {
        kills = s_bt_bod_guard & 0xFFu;
    }
    s_bt_bod_guard = 0;
    return kills;
}

// Drain the ADC and feed the DAC one I2S block. Passed to es8388_init() so the
// I2S DMA stays serviced during I2C config; an unserviced DMA storms the CPU and
// trips the watchdog. Runs before audio_pipeline_start(), so nothing else touches
// I2S yet. It's also a raw RX->TX loopback, so the GBA's analog feed already
// passes to the DAC during codec config (inaudible until the amp is unmuted).
static void codec_service_i2s(void)
{
    static int32_t buf[256 * 2];
    size_t br = 0, bw = 0;
    if (i2s_codec_read(buf, sizeof(buf), &br, 50) == ESP_OK && br) {
        i2s_codec_write(buf, br, &bw, 50);
    }
}

// Hold-to-wake gate. The Connect/Pair button is tapped off the GBA R shoulder
// net and is also an EXT1 deep-sleep wake source, so a gameplay tap would
// otherwise wake the chip and spin up BT. On an EXT1 wake, require the button
// held for CONFIG_GBHIFI_WAKE_HOLD_S; a shorter press re-arms the wake sources and
// returns to deep sleep before any heavy init runs. PIN_PAM_SD stays RTC-held
// across the bounce so the speaker state is preserved.
static void gate_cp_wake(void)
{
    if (esp_sleep_get_wakeup_cause() != ESP_SLEEP_WAKEUP_EXT1) {
        return;  // cold boot or HP-detect (EXT0) wake
    }

    // Reclaim the button and HP pins from the RTC mux so we can read them.
    rtc_gpio_deinit(PIN_CP_BUTTON);
    rtc_gpio_deinit(PIN_HP_DETECT);
    gpio_config_t in = {
        .pin_bit_mask = (1ULL << PIN_CP_BUTTON) | (1ULL << PIN_HP_DETECT),
        .mode         = GPIO_MODE_INPUT,
        .pull_up_en   = GPIO_PULLUP_DISABLE,   // HP by R10 on-board, CP off-board (see pinmap.h)
        .pull_down_en = GPIO_PULLDOWN_DISABLE,
        .intr_type    = GPIO_INTR_DISABLE,
    };
    ESP_ERROR_CHECK(gpio_config(&in));

    ESP_LOGI(TAG, "Connect/Pair wake: hold %d s to confirm (else back to sleep)",
             CONFIG_GBHIFI_WAKE_HOLD_S);
    for (int i = 0; i < CONFIG_GBHIFI_WAKE_HOLD_S * 50; i++) {
        if (gpio_get_level(PIN_CP_BUTTON) != 0) {  // released: game input
            ESP_LOGI(TAG, "button released after %d ms, back to sleep", i * 20);
            // Re-arm the same wake sources as DEEP_IDLE entry: ext0 on HP at the
            // opposite of its current level, ext1 on R LOW. Keep PIN_PAM_SD held.
            int hp_wake_level = (gpio_get_level(PIN_HP_DETECT) == 1) ? 0 : 1;
            ESP_ERROR_CHECK(esp_sleep_enable_ext0_wakeup(PIN_HP_DETECT,
                                                         hp_wake_level));
            ESP_ERROR_CHECK(esp_sleep_enable_ext1_wakeup(
                1ULL << PIN_CP_BUTTON, ESP_EXT1_WAKEUP_ALL_LOW));
            gpio_deep_sleep_hold_en();
            esp_deep_sleep_start();
        }
        vTaskDelay(pdMS_TO_TICKS(20));
    }
    ESP_LOGI(TAG, "button held, wake confirmed");
}

// Boot-time factory reset: if the Connect/Pair button (active LOW) is held from
// power-on for CONFIG_GBHIFI_FACTORY_RESET_S seconds, clear all bonded sinks.
// Releasing it before the deadline aborts. Runs after buttons_init and
// bt_a2d_init.
static void maybe_factory_reset(void)
{
    // Only on a true power cycle (GBA rail applied). A software reset that happens
    // to leave the button held must NOT count -- notably the Mode A -> B exit,
    // which reboots the instant the R-hold hits its threshold, with the button
    // still down. Without this gate the user, still holding R and waiting for the
    // "full mode" chime, would slide straight into the factory-reset countdown.
    if (esp_reset_reason() != ESP_RST_POWERON) {
        return;
    }
    if (gpio_get_level(PIN_CP_BUTTON) != 0) {
        return;  // button not held at boot
    }
    // PIN_CP_BUTTON has no pull-up on either board and GPIO34 has no internal
    // one, so an unconnected PAIR wire floats and reads exactly like a held
    // button. Require the battery rail before believing it: with no rail the
    // board is on the programming header, where nobody is holding anything.
    // Without this every bench visit silently wipes a repaired unit's bonds.
    if (!harness_rail_present()) {
        ESP_LOGW(TAG, "Connect/Pair reads held but the battery rail is absent; "
                      "treating it as an open PAIR line, not a factory reset");
        return;
    }
    ESP_LOGW(TAG, "Connect/Pair held at boot, keep holding %d s for factory reset",
             CONFIG_GBHIFI_FACTORY_RESET_S);
    for (int i = 0; i < CONFIG_GBHIFI_FACTORY_RESET_S * 10; i++) {
        vTaskDelay(pdMS_TO_TICKS(100));
        if (gpio_get_level(PIN_CP_BUTTON) != 0) {
            ESP_LOGI(TAG, "button released, factory reset aborted");
            return;
        }
    }
    ESP_LOGW(TAG, "factory reset: clearing all bonds");
    bt_a2d_clear_bonds();
}

// Anti-brick confirmation for OTA. A freshly OTA'd image boots in PENDING_VERIFY;
// reaching this point means init completed without a panic, so mark the image
// good and cancel the pending rollback. A bad image that panics during init
// never gets here and the bootloader reverts on the next reset. The gate is
// "init completed" rather than a runtime milestone because the mod sits on the
// GBA switched rail and power-cycles constantly. Cable-flashed images boot
// UNDEFINED (rollback not armed), so this is a no-op for them.
static void ota_confirm_image_valid(void)
{
    const esp_partition_t *run = esp_ota_get_running_partition();
    esp_ota_img_states_t state;
    if (!run || esp_ota_get_state_partition(run, &state) != ESP_OK) return;
    if (state != ESP_OTA_IMG_PENDING_VERIFY) return;
    if (esp_ota_mark_app_valid_cancel_rollback() == ESP_OK) {
        ESP_LOGW(TAG, "OTA image on %s confirmed good, rollback cancelled", run->label);
    } else {
        ESP_LOGE(TAG, "esp_ota_mark_app_valid_cancel_rollback failed");
    }
}

void app_main(void)
{
    ESP_LOGI(TAG, "GameBoy HiFi v%s booting", esp_app_get_description()->version);

    // Read + clear the BT brownout guard first, before anything else can reset
    // us, so the count only ever reflects BODs inside the armed radio window.
    uint32_t bod_kills = bt_bod_kills();

    // Log the wake cause so the UART trace shows cold boot vs HP-plug (ext0) vs
    // R-button (ext1). The boot path is the same in all cases.
    esp_sleep_wakeup_cause_t cause = esp_sleep_get_wakeup_cause();
    switch (cause) {
    case ESP_SLEEP_WAKEUP_EXT0: {
        // EXT0 polarity is set at sleep entry to the opposite of the HP level,
        // so on wake the line is at the level that triggered it.
        int lvl = gpio_get_level(PIN_HP_DETECT);
        ESP_LOGI(TAG, "wake cause: EXT0 (HP %s, GPIO35 now %s)",
                 lvl ? "plug" : "unplug", lvl ? "HIGH" : "LOW");
        break;
    }
    case ESP_SLEEP_WAKEUP_EXT1: {
        uint64_t mask = esp_sleep_get_ext1_wakeup_status();
        ESP_LOGI(TAG, "wake cause: EXT1 (mask=0x%" PRIx64 ", R-button)", mask);
        break;
    }
    default:
        ESP_LOGI(TAG, "wake cause: cold boot (reason %d)", (int)cause);
        break;
    }

    // On an EXT1 wake, confirm an intentional hold before expensive init.
    gate_cp_wake();

    // Boot-mute the speaker amp. Its SD divider floats to "enabled", so without
    // this the amp runs before the DAC is clocking valid samples and pops. Cold
    // boot only: on a deep-sleep wake the pin is still RTC-held from before sleep,
    // and app_sm releases the hold and re-applies the mute policy.
    if (cause == ESP_SLEEP_WAKEUP_UNDEFINED) {
        gpio_config_t amp_sd = {
            .pin_bit_mask = 1ULL << PIN_PAM_SD,
            .mode         = GPIO_MODE_OUTPUT,
            .pull_up_en   = GPIO_PULLUP_DISABLE,
            .pull_down_en = GPIO_PULLDOWN_DISABLE,
            .intr_type    = GPIO_INTR_DISABLE,
        };
        ESP_ERROR_CHECK(gpio_config(&amp_sd));
        gpio_set_level(PIN_PAM_SD, 0);
    }

    // NVS holds the BT controller PHY calibration and the Bluedroid bond keys.
    esp_err_t nvs = nvs_flash_init();
    if (nvs == ESP_ERR_NVS_NO_FREE_PAGES || nvs == ESP_ERR_NVS_NEW_VERSION_FOUND) {
        ESP_ERROR_CHECK(nvs_flash_erase());
        nvs = nvs_flash_init();
    }
    ESP_ERROR_CHECK(nvs);

    // Bring up the I2S master bus first so the ES8388 sees MCLK before its I2C
    // config runs (the codec won't start its state machine without MCLK). Settle,
    // then configure over I2C. The production PCB's series-R + short MCLK routing
    // keep the writes clean, so no read-back verify pass is needed.
    ESP_ERROR_CHECK(i2s_codec_init());
    ESP_ERROR_CHECK(i2s_codec_start());
    vTaskDelay(pdMS_TO_TICKS(30));
    ESP_ERROR_CHECK(es8388_init(codec_service_i2s));

    // Codec configured; unmute the speaker amp now, before the DSP pipeline and
    // the deferred BT bring-up. The amp comes up on the audio path alone so the
    // Game Boy power-on chime plays the earliest possible moment; app_sm_start()
    // re-evaluates the amp against the real HP/state once it runs.
    app_sm_speaker_early_on();

    // DSP subsystem, ready before the pipeline task calls into it: settings holds
    // the parameter snapshot, fs mounts the clip store, sfx owns the cue feeder,
    // dsp seeds its coefficients from settings.
    ESP_ERROR_CHECK(settings_init());
    ESP_ERROR_CHECK(fs_init());
    ESP_ERROR_CHECK(sfx_init());

    // Seed the speaker volume from the wheel before dsp_init reads it, so the very
    // first audio block comes out at the wheel setting. Otherwise the wheel isn't
    // read until app_sm_start()'s poll (behind the BT hold-off below), and a
    // wheel-down user hears the stored default volume blare on every power-cycle.
    app_sm_prime_volume();

    ESP_ERROR_CHECK(dsp_init());

    // Seed the local-path EQ profile (Speaker vs Headphone) from the HP state
    // app_sm_speaker_early_on() already sampled, so the startup chime is voiced for
    // the live output from its first block. sm_task re-applies this on the live pin.
    dsp_set_hp_plugged(app_sm_hp_plugged());

    // Mod startup chime: play our own clean, complete chime clip over a muted live
    // passthrough, so the user hears one full chime instead of the truncated live
    // GBA chime (the codec/amp miss its first ~0.9 s of boot). dsp_begin_intro()
    // mutes the passthrough until the clip ends; sfx_trigger_clip() streams it.
    // Gated on sfx_enabled and startup_mode: with cues off, or the mode set to
    // STARTUP_OFF, this block does not run and the GBA's own chime plays through
    // untouched, missing its first ~0.9 s. STARTUP_ORIGINAL is that same chime
    // complete, as a clip. Both calls run before audio_pipeline_start(), i.e.
    // before the audio task exists, so the passthrough is muted from block one.
    // Voice the startup chime only on a genuine power cycle. Every other reset --
    // a Mode A/B change reboot (esp_restart, ESP_RST_SW), a watchdog, a brownout --
    // re-runs this boot path but should be silent: the user didn't power the console
    // on, and (for a mode-change reboot) the GBA never lost power, so the muted-
    // passthrough intro would just swallow the live game audio for no reason.
    gbhifi_settings_t boot_s;
    settings_get(&boot_s);
    bool power_on = (esp_reset_reason() == ESP_RST_POWERON);
    // Boot-mode decision (made once, gates BT init + the chime, handed to app_sm). A
    // Mode A boot keeps the radio off (battery mode + clean light sleep) and drops
    // STRAIGHT into Mode A -- no chime, no pause. A real power cycle consults the
    // persist flag; a mode-change reboot (SW reset) always lands in the saved mode.
    // Holding CP (R) at power-on forces Mode B -- the only Mode A boot escape.
    // Enable the button pad's input buffer before sampling: on a cold boot
    // nothing has configured it yet (gate_cp_wake only does on an EXT1 wake),
    // and an unconfigured input-only pad reads 0 -- a phantom "held" that
    // would divert the boot to Mode B. buttons_init() reconfigures the same
    // pad with interrupts later.
    rtc_gpio_deinit(PIN_CP_BUTTON);
    gpio_config_t cp = {
        .pin_bit_mask = 1ULL << PIN_CP_BUTTON,
        .mode         = GPIO_MODE_INPUT,
        .pull_up_en   = GPIO_PULLUP_DISABLE,   // held HIGH off-board by the AGB keypad pull-up
        .pull_down_en = GPIO_PULLDOWN_DISABLE,
        .intr_type    = GPIO_INTR_DISABLE,
    };
    ESP_ERROR_CHECK(gpio_config(&cp));
    bool cp_held = (gpio_get_level(PIN_CP_BUTTON) == 0);   // active LOW
    bool boot_mode_a = boot_s.mode_a && !cp_held &&
                       (!power_on || boot_s.boot_mode_a);
    ESP_LOGI(TAG, "boot-mode decision: mode_a=%d cp_held=%d reset=%d power_on=%d "
             "persist=%d -> %s", boot_s.mode_a, cp_held, esp_reset_reason(),
             power_on, boot_s.boot_mode_a, boot_mode_a ? "A" : "B");
    app_sm_set_boot_into_mode_a(boot_mode_a);
    if (boot_mode_a) {
        ESP_LOGI(TAG, "Mode A boot: skipping BT init + chime (BT-less battery mode)");
    }
    // Voice the startup chime only on a genuine power cycle into Mode B. Any other
    // reset (mode-change reboot, watchdog, brownout) re-runs this boot path silently.
    // NULL == STARTUP_OFF, which takes the cues-disabled path: no intro mute, no
    // clip, and the BT hold-off below is skipped since it exists only to keep the
    // radio off the chime.
    const char *startup_clip = settings_startup_clip(boot_s.startup_mode);
    bool use_mod_chime = boot_s.sfx_enabled && power_on && !boot_mode_a && startup_clip;
    if (use_mod_chime) {
        dsp_begin_intro();
        sfx_trigger_clip(startup_clip);
    }

    ESP_ERROR_CHECK(audio_pipeline_start());

    ESP_ERROR_CHECK(buttons_init());

    // Confirm a pending OTA image good as soon as the audio path is up, BEFORE the
    // BT delay below. The mod sits on the GBA's switched rail and power-cycles
    // constantly; gating this behind the ~3.5 s BT hold-off would let a power-cycle
    // during that window roll back an otherwise-good image.
    ota_confirm_image_valid();

    // A Mode A boot keeps the radio off entirely -- battery mode plus a clean,
    // conflict-free light-sleep loop -- so skip the whole BT bring-up below. Mode B
    // (and the Mode A escape window, which runs in Mode B local) bring the radio up.
    if (!boot_mode_a) {
    // Defer the Bluetooth controller + radio until CONFIG_GBHIFI_BT_START_DELAY_MS
    // after power-on, but ONLY when the startup chime is playing: the whole point of
    // the hold-off is to let the chime finish before the radio's inrush + PHY spike
    // land (they'd otherwise sag the boost rail under the chime's peak). A silent
    // reboot (mode change / watchdog) has no chime, so the delay is pure dead time
    // that shows up as an audible gap before Mode B audio fully comes up -- skip it
    // and bring BT + app_sm (final routing) up immediately.
    if (use_mod_chime) {
        int64_t elapsed_ms = esp_timer_get_time() / 1000;
        if (elapsed_ms < CONFIG_GBHIFI_BT_START_DELAY_MS) {
            vTaskDelay(pdMS_TO_TICKS(CONFIG_GBHIFI_BT_START_DELAY_MS - elapsed_ms));
        }
        // ...then keep holding until the startup chime has fully drained, so the
        // PHY-calibration spike doesn't land on the chime's final second. Capped so
        // a wedged cue can't block BT forever (chime is ~3.5 s, starts ~1 s in).
        for (int i = 0; sfx_cue_active() && i < 100; i++) {
            vTaskDelay(pdMS_TO_TICKS(50));
        }
    }

    if (bod_kills >= BT_BOD_MAX_TRIES) {
        // The radio brownout-reset the last BT_BOD_MAX_TRIES boots in a row: the
        // battery can't carry the PHY power-up. Come up local-only instead of
        // boot-looping; the bt_a2d_* API is guarded to no-op un-inited. A real
        // power cycle (battery change) scrambles RTC noinit and re-arms BT.
        ESP_LOGE(TAG, "BT radio brownout-reset the last %" PRIu32 " boots -- battery "
                 "too low for the radio, staying LOCAL-ONLY (power-cycle to retry)",
                 bod_kills);
    } else {
        if (bod_kills > 0) {
            // One strike: give the rail extra quiet time, then try once more.
            ESP_LOGW(TAG, "last boot brownout-reset during BT radio init "
                     "(attempt %" PRIu32 "/%d), retrying after settle",
                     bod_kills, BT_BOD_MAX_TRIES);
            vTaskDelay(pdMS_TO_TICKS(2000));
        }

        // Park the speaker amp for the radio bring-up window so the PHY spike is
        // the only load transient on the boost; the chime is done (waited out
        // above), so at most a sub-second gap in the live passthrough.
        app_sm_amp_radio_quiet(true);
        vTaskDelay(pdMS_TO_TICKS(250));   // let the amp/rail settle before the spike

        s_bt_bod_guard = BT_BOD_MAGIC | (bod_kills + 1);
        ESP_ERROR_CHECK(bt_a2d_init());

#if CONFIG_GBHIFI_BLE_CONFIG
        // BLE GATT config server alongside the A2DP source (controller in BTDM dual
        // mode). Comes up after bt_a2d_init() since Bluedroid is enabled there.
        ESP_ERROR_CHECK(ble_config_init());
#endif
        s_bt_bod_guard = 0;   // radio survived: disarm the loop breaker

        app_sm_amp_radio_quiet(false);
    }
    }   // end if (!boot_mode_a)

    // Factory reset before the state machine starts: Connect/Pair held from
    // power-on clears all bonds, dropping the next boot into pairing.
    maybe_factory_reset();

    ESP_ERROR_CHECK(app_sm_start());

    // Install diagnostics. The report is logged at every boot: on an installed
    // unit it is four ok lines, and on the bench it is the QA pass, naming the
    // connector pin behind each bad signal.
    ESP_ERROR_CHECK(harness_init());
    {
        harness_report_t rep;
        harness_eval(&rep);
        harness_log_report(&rep);
    }

    // UART REPL control surface, started last. The web UI (BLE config) drives the
    // same settings_* API. Needs an interactive serial monitor for input.
    ESP_ERROR_CHECK(console_start());

    while (1) {
        vTaskDelay(pdMS_TO_TICKS(60000));
        ESP_LOGI(TAG, "alive (free heap: %" PRIu32 " B, min ever: %" PRIu32 " B)",
                 esp_get_free_heap_size(), esp_get_minimum_free_heap_size());
        app_sm_batt_check();
    }
}

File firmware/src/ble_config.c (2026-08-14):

#include "ble_config.h"

#include "sdkconfig.h"

#if CONFIG_GBHIFI_BLE_CONFIG

#include <stdio.h>
#include <string.h>
#include <unistd.h>

#include "esp_bt.h"
#include "esp_gap_ble_api.h"
#include "esp_gatts_api.h"
#include "esp_gatt_common_api.h"
#include "esp_log.h"
#include "esp_timer.h"
#include "esp_system.h"

#include "esp_ota_ops.h"     // OTA: esp_ota_begin/write/end, partition select
#include "esp_app_desc.h"    // OTA: running app version for GET_INFO
#include "esp_rom_crc.h"     // OTA: incremental crc32 sanity check

#include "freertos/FreeRTOS.h"
#include "freertos/task.h"
#include "freertos/queue.h"
#include "freertos/stream_buffer.h"

#include "esp_console.h"     // BLE console: esp_console_run() reuses the UART cmd table

#include <stdarg.h>
#include <stdlib.h>

#include "fs.h"
#include "settings.h"
#include "sfx.h"
#include "audio_pipeline.h"   // spectrum tap for the BLE web visualizer
#include "app_sm.h"           // app_sm_hp_plugged(): distinguishes speaker vs headphone for the spectrum source byte
#include "harness.h"          // install diagnostics served on the DIAG characteristic

static const char *TAG = "ble_cfg";

#define BLE_DEVICE_NAME   "GameBoy HiFi Setup"
#define BLE_APP_ID        0x42
#define ACTION_MAX_LEN    40         // opcode + clip-name room

// ---- GATT schema ----------------------------------------------------------
// Custom 128-bit UUIDs, stored LSB-first as Bluedroid expects.
//   service:  5a4d0000-1f2e-4c6b-9a8f-0102030405aa
//   settings: 5a4d0001-...   (R/W/Notify, packed gbhifi_settings_t mirror)
//   action:   5a4d0002-...   (Write: save / chime / play)
static const uint8_t SVC_UUID128[16] = {
    0xaa, 0x05, 0x04, 0x03, 0x02, 0x01, 0x8f, 0x9a,
    0x6b, 0x4c, 0x2e, 0x1f, 0x00, 0x00, 0x4d, 0x5a,
};
static const uint8_t SETTINGS_UUID128[16] = {
    0xaa, 0x05, 0x04, 0x03, 0x02, 0x01, 0x8f, 0x9a,
    0x6b, 0x4c, 0x2e, 0x1f, 0x01, 0x00, 0x4d, 0x5a,
};
static const uint8_t ACTION_UUID128[16] = {
    0xaa, 0x05, 0x04, 0x03, 0x02, 0x01, 0x8f, 0x9a,
    0x6b, 0x4c, 0x2e, 0x1f, 0x02, 0x00, 0x4d, 0x5a,
};
//   otactl:  5a4d0003-...   (Write + Notify: OTA control / status)
//   otadata: 5a4d0004-...   (Write-no-response: raw firmware chunks)
static const uint8_t OTACTL_UUID128[16] = {
    0xaa, 0x05, 0x04, 0x03, 0x02, 0x01, 0x8f, 0x9a,
    0x6b, 0x4c, 0x2e, 0x1f, 0x03, 0x00, 0x4d, 0x5a,
};
static const uint8_t OTADATA_UUID128[16] = {
    0xaa, 0x05, 0x04, 0x03, 0x02, 0x01, 0x8f, 0x9a,
    0x6b, 0x4c, 0x2e, 0x1f, 0x04, 0x00, 0x4d, 0x5a,
};
//   log:     5a4d0005-...   (Notify: device -> client ESP_LOG / console stream)
//   cmd:     5a4d0006-...   (Write / Write-NR: client -> device console line)
static const uint8_t LOG_UUID128[16] = {
    0xaa, 0x05, 0x04, 0x03, 0x02, 0x01, 0x8f, 0x9a,
    0x6b, 0x4c, 0x2e, 0x1f, 0x05, 0x00, 0x4d, 0x5a,
};
static const uint8_t CMD_UUID128[16] = {
    0xaa, 0x05, 0x04, 0x03, 0x02, 0x01, 0x8f, 0x9a,
    0x6b, 0x4c, 0x2e, 0x1f, 0x06, 0x00, 0x4d, 0x5a,
};
//   spec:    5a4d0007-...   (Notify: stereo live audio spectrum, L bands + R bands)
static const uint8_t SPEC_UUID128[16] = {
    0xaa, 0x05, 0x04, 0x03, 0x02, 0x01, 0x8f, 0x9a,
    0x6b, 0x4c, 0x2e, 0x1f, 0x07, 0x00, 0x4d, 0x5a,
};
//   diag:    5a4d0008-...   (Read + Notify: packed harness install report)
static const uint8_t DIAG_UUID128[16] = {
    0xaa, 0x05, 0x04, 0x03, 0x02, 0x01, 0x8f, 0x9a,
    0x6b, 0x4c, 0x2e, 0x1f, 0x08, 0x00, 0x4d, 0x5a,
};
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

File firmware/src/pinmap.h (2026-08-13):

#pragma once

// Single source of truth for all pin assignments. Do not hard-code GPIO
// numbers anywhere else.
//
// Board: ESP32-PICO-MINI-02 with the ES8388 codec on a full-duplex I2S master
// bus plus I2C control.

// ----- I2S0: full-duplex master to the ES8388 -----
// The ESP32 masters the bus and generates MCLK, BCLK, and LRCK; the ES8388 is
// the I2S slave. MCLK comes off the APLL on GPIO0 (the only free MCLK-capable
// pin; GPIO1/3 are the console UART) and reaches the codec through a series
// resistor. DIN/DOUT are named from the ESP32 side: our DOUT drives the codec
// DAC input (DSDIN), our DIN reads the codec ADC output (ASDOUT).
#define PIN_I2S_MCLK     0   // ES8388 MCLK (APLL)
#define PIN_I2S_BCK     25   // shared bit clock
#define PIN_I2S_LRCK    26   // shared word/LR clock
#define PIN_I2S_DOUT    27   // to ES8388 DSDIN (DAC playback)
#define PIN_I2S_DIN     14   // from ES8388 ASDOUT (ADC capture)

// ----- I2C0: ES8388 control (address 0x10) -----
#define PIN_I2C_SDA     21
#define PIN_I2C_SCL     22

// ----- Analog input: GBA volume wheel (VR2 wiper) -----
// Read on ADC1; GPIO39 is input-only. In Mode B the wheel sets the DSP digital
// volume; in Mode A it sets the ES8388 analog-bypass volume over I2C. The wheel
// is powered from VBAT, so its reading is battery-referenced (see PIN_VBAT_ADC).
#define PIN_VOL_ADC     39

// ----- Analog input: battery-rail sense -----
// VBAT (the GBA battery rail feeding the U3 boost) through an R20/R21 = 100k/100k
// divider into ADC1_CH0 (GPIO36, input-only). VBAT = 2 * V(PIN_VBAT_ADC). Shares
// the ADC1 oneshot unit with the volume wheel.
#define PIN_VBAT_ADC    36

// ----- Control outputs -----
// External mono speaker-amp shutdown/mute (active HIGH = amp enabled).
// app_sm asserts mute when BT is STREAMING or wired HP is plugged.
#define PIN_PAM_SD       4

// ----- Wake-source inputs (RTC GPIOs, input-only) -----
// The two are not wired alike: HP-detect has a pull-up on the mod PCB, the
// Connect/Pair line has none anywhere. Do not group them.
//
// Connect/Pair button: the mod's control input (connect / pair, deep-sleep
// wake, boot-time factory reset). Tapped off the GBA R shoulder net.
// The PAIR net is just U1 pin 9 and FPC1 pin 9: no pull-up on the mod PCB, none
// on the flex, and GPIO34 has no internal pull. What holds it HIGH is the AGB
// CPU's own keypad pull-up, reached through the hand-soldered wire at flex J4.
// So with the flex off, or that wire unsoldered, this pin floats and reads LOW,
// which is indistinguishable from a held button. harness.c calls that out and
// main.c refuses to factory-reset on it without a battery rail.
#define PIN_CP_BUTTON   34   // LOW = pressed (held HIGH by the AGB keypad pull-up, off-board)

// HP-detect. Polarity is inverted vs a typical detect line: the GBA's internal
// headphone-jack switch grounds this sense line when nothing is plugged in.
// R10 10k to +3V3 on the mod PCB pulls it up (through the R11 1k / C22 10n RC),
// so the ESP32 reads HIGH = plugged, LOW = unplugged. That pull-up sits upstream
// of FPC1, so an unplugged flex also reads HIGH: "plugged" and "sense line open"
// are the same level here, and only context separates them (see harness.c).
#define PIN_HP_DETECT   35   // HIGH = headphones plugged, LOW = unplugged

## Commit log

2026-07-22 hardware(agb): reroute mod PCB for the smaller shell fit; trim + reinforce FPC lead
    Mod PCB: full reroute after narrowing the outline 28.5mm -> 25.35mm to fit the
    shell. U2 (codec) moved and rotated 90deg with NT1 following; fiducials dropped
    (sub-70x70 boards ride JLCPCB rails, which carry their own). Layout review
    verified clean: DRC 0 unconnected, antenna keep-outs intact with the module
    antenna overhanging the edge, zones refilled, power widths unchanged.
    FPC: lead tip trimmed 1.25mm (y128 -> y126.75) to clear the volume wheel --
    1.6mm is the geometric max without moving the J5 finger pattern, and the
    shorter setback lands closer to the Hirose copper-to-tip recommendation.
    Stiffener pul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
    [agb-hifi-audio-fpc.kicad_pcb, agb-hifi-audio-fpc.stl, agb-hifi-audio-pcb.kicad_pcb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]
2026-07-22 hardware(agb): switch FPC1 to JUSHUO AFC07-S12ECA-00
    The Hirose FH12A-12S-0.5SH(55) is out of stock at JLCPCB/LCSC (2 pcs left),
    which blocks assembly. Replace it with the JUSHUO AFC07-S12ECA-00 (LCSC
    C262585, ~19k stock): same 12-pos 0.5mm top-contact ZIF at the same 2.0mm
    height, and the flex tail meets its mating spec (0.3mm thickness, 3.5mm
    exposure vs 3.0 minimum, 6.5mm width).
    Not a drop-in: the AFC07 fitting nails sit 2.26mm from the pin row vs the
    Hirose's 3.25mm, on top of the old VOL/SW/PAIR and VBAT fanout channel, so
    those nets are rerouted around the new nail lands. Pin row and net order are
    unchanged; the flex geometry is untouched. DRC is clean (0 unconnected, no
    live violati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
    [agb-hifi-audio-pcb.kicad_pcb, agb-hifi-audio-pcb.kicad_sch, agb-hifi-audio-pcb.stl]
2026-07-22 docs: re-render board images for the 1.1 reroute, white mask + black silk
    New renders of both boards after the outline change, reroute, and AFC07
    connector swap, switched from the purple scheme to white solder mask with
    black silkscreen. The flex render picks up the shortened lead and the base
    fillets; the main-board bottom now shows the AFC07 at FPC1. Rendered with
    kicad-cli at high quality from stackup-colored copies of the boards.
2026-07-22 hardware(agb): trim FPC lead a further 1.25 mm (2.5 mm total)
    Shorten the connector lead to y125.5 (from y126.75), reaching the 2.5 mm total
    trim that clears the volume wheel with margin. This pass moves the J5 finger
    pattern up 1.2 mm with the edge (origin y126.4 -> y125.2, pad tips y125.2,
    0.3 mm from the board edge), since the first 1.25 mm pass had already reached
    the limit of a length-only cut. Stiffener follows flush at y120.675-125.5
    (4.825 mm coverage, above the 4.5 mm Hirose minimum). Flex is now 23.1 x
    34.8 mm. DRC clean; JLCPCB production files re-exported.
    [agb-hifi-audio-fpc.kicad_pcb, agb-hifi-audio-fpc.stl]
2026-07-22 docs(agb-install): add flex-install video, simplify speaker step
    Add a Video walkthrough section near the top linking the flex-install video
    (clickable YouTube thumbnail, since GitHub Markdown can't embed iframes).
    Replace the Choosing the speaker section with a single instruction to reattach
    the GBA's own stock speaker to the mod PCB SPK+/SPK- pads (not the GBA
    mainboard). The aftermarket-driver sourcing notes moved to
    history/SPEAKER-FINDINGS.md for later reference.
2026-07-23 hardware(agb): set solder-mask min web width to 0.25mm; ignore pcbway/
    Set the board's solder-mask minimum sliver width to 0.25mm (Board Setup), above
    PCBWay's 0.22mm floor. This merges the ~0.2mm mask webs between U2's fine-pitch
    QFN-28 pins into gang openings, which PCBWay flagged as unmanufacturable. The
    setting is honored by kicad-cli exports (the PCBWay plugin ignores it).
    Gitignore hardware/**/pcbway/ (the real export dir name; the prior
    pcbway-gerbers/ pattern never matched), matching how jlcpcb/ is ignored.
    [agb-hifi-audio-pcb.kicad_pcb]
2026-07-24 docs: add JLCPCB fab order settings for the flex
    Record the JLCPCB order-form settings for the flex (material, ENIG, coverlay,
    stiffener, EMI) so reorders stay consistent, and link it from HARDWARE.md's
    ordering section. Main-board settings left as a stub to capture on next order.
2026-07-26 hardware(agb): widen U6 amp-footprint slots to 0.4mm for fab minimum
    Increase the 20 slot drills on the AGB AMP CONNECT footprint from 2.2x0.3mm to
    2.2x0.4mm (pad 0.5->0.6mm) to clear the fab's minimum slot width. DRC clean, 0
    unconnected.
    [agb-hifi-audio-fpc.kicad_pcb]
2026-07-27 hardware(agb): open the flex coverlay on the back of the U6 slots
    JLCPCB flagged the 20 slots on the AGB AMP CONNECT footprint as having no
    solder-mask opening on the back side, leaving them covered from below. The flex
    solders to the GBA's freed U6 lands by flowing solder down through those slots,
    so a covered back blocks the joint. Change the pads from *.Cu/F.Mask/F.Paste to
    *.Cu/*.Mask/F.Paste in the board and in the library footprint; back openings
    match the pads (0.6x2.5mm) and keep the same 0.2mm coverlay web the top already
    has. DRC clean, 0 unconnected.
    [agb-hifi-audio-fpc.kicad_pcb]
2026-07-27 hardware(agb): move the GND ties near the U6 slots to F.Cu, loosen the zone fill
    Board-side layout change made in KiCad: drop three B.Cu GND segments around
    x=94.3 (y 100.2-104.4) and run GND on F.Cu instead, with new stitching vias
    (0.6/0.3) at (94.3, 104.175) and (98.3, 108.475). The GND zone's min_thickness
    goes 0.25 -> 0.1 mm and connect_pads clearance 0.5 -> 0.1 mm so the pour reaches
    into the tighter gaps; zone defaults in the .kicad_pro follow. DRC clean.
    [agb-hifi-audio-fpc.kicad_pcb]
2026-07-27 hardware(agb): restore the back coverlay openings on the U6 slots
    Reapply 899f090 on the board. A KiCad save from a session opened before that
    commit wrote the board back out with the 20 J1 pads on F.Mask only, dropping the
    back openings; the library footprint kept them, so the board also disagreed with
    its own library. Pads are back to *.Cu/*.Mask/F.Paste. DRC clean, 0 unconnected,
    JLCPCB files re-exported on top of the F.Cu GND change.
    [agb-hifi-audio-fpc.kicad_pcb]
2026-07-27 hardware(agb): single 0.4mm VBAT run down the lead, solid zone pad connection
    Replace the two parallel 0.2 mm VBAT traces down the connector lead (x=83.05 and
    x=83.55, y108.65-124) with one 0.4 mm trace on the centreline (x=83.3,
    y108.4-121.4), fanning back out to the two J5 fingers with 0.2 mm 45-degree stubs
    at y121.4-123.45. Zone pad connection goes from thermal reliefs to solid
    (connect_pads yes, pad_connection 2 in the .kicad_pro). DRC clean, 0
    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
    [agb-hifi-audio-fpc.kicad_pcb]
2026-07-27 hardware(agb): spell out the stiffener requirement on the JLC layer, drop the thickness from its name
    The fab asked where the stiffener goes even though the layer was in the package:
    inside the outline it was just an unlabelled rectangle, and the only note was
    mirrored and floating well outside the board.
    Rename the User.3 layer JLC_Stiffener_Bottom_0.2mm -> JLC_Stiffener_Bottom, so
    the design stops implying a stackup the fab may not stock. What the design needs
    is the total finished thickness at the fingers, 0.30 +/-0.05 mm; each fab picks a
    stiffener that hits it. Rewrite the note on that layer unmirrored so it reads in
    a normal top-down CAM view, carrying the relevant detail from the gen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
    [agb-hifi-audio-fpc.kicad_pcb]
2026-07-27 hardware(agb): carry the fabrication notes onto the JLC stiffener layer
    Cmts.User holds the general fabrication notes and is what PCBWay gets, but that
    layer is not in the JLCPCB export, so JLC has only ever received copper, mask,
    silk, outline and the stiffener rectangle. Copy the notes that a fab acts on onto
    User.3 (JLC_Stiffener_Bottom), the one user layer that does ship: material and
    copper weight, ENIG coverage, coverlay both sides, the intentional edge-metallized
    lands, critical dimensions, the one-time fold, min trace/space, and electrical
    test. Numbering follows the Cmts.User block, with item 4 pointing at the stiffener
    note beside the tail. Placed to the right of the outline, unmir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
    [agb-hifi-audio-fpc.kicad_pcb]
2026-08-13 firmware(agb): install diagnostics for the four GBA-facing signals
    New harness module classifies VBAT, VOL, PAIR and HP independently as ok, open,
    unclear or unknown, each with the measured value and the connector pin to check,
    so a partial misconnection reads differently from a board sitting on the bench.
    Reported in the boot log, a new `diag` console command, and a DIAG GATT
    characteristic (read + notify) behind an Install check card on the web System
    tab, which badges the System nav entry while any signal reads open.
    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
2026-08-13 firmware(agb): 2/4/6-order reconstruction low-pass on the capture path, default 6.7 kHz steep
    The NR low-pass is now a Butterworth cascade (nr lpf <hz> [order 2|4|6]).
    With the corner at a game's PCM Nyquist the steep slopes cut the GBA's
    nearest-neighbor resampling images the way an emulator's sinc interpolation
    does; the analog tap can't resample, so the filter is the post-hoc
    equivalent. Defaults on at 6700 Hz order 6, chosen by ear on Metroid Fusion.
    Settings blob v14 carries the corner and order over BLE (bytes 35-37).
    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
2026-08-13 web: smoothing filter slider
    One slider, six stops from off to a 4.2 kHz deep cut, mapped to the new
    reconstruction low-pass. Shows the device's real corner and order, snaps a
    console-tuned custom value to the nearest stop without overwriting it, and
    grays out on firmware older than settings v14.
2026-08-14 firmware(agb): stop running the BT DSP when nothing is streaming; drop runtime stats
    Two audio regressions found on the bench after 1.2.0.
    The boot chime was chopped: dsp_process_bt ran the whole NR chain every block
    even with no A2DP sink connected, and the result was discarded -- the push
    into the stream buffer is gated on s_bt_streaming. With the reconstruction
    LPF that waste is a dozen biquad passes per block, enough to blow the 5.8 ms
    budget while the boot init storm ran. The pipeline now calls it only while a
    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
2026-08-14 web: check a dropped firmware image before sending it
    The device already refuses an image whose app-descriptor project name is not
    ours, but only after the whole transfer, with the audio stopped for it. Read
    the same fields host-side and refuse in the file picker instead: image magic,
    app-descriptor magic, project name, and a size that fits the app slot. The
    cable-only full-flash image is named specifically, since both files ship in
    the same release. Strings out of the file are filtered before display.
2026-08-14 firmware(agb): stop the task watchdog from chopping audio during A2DP
    The whole Bluetooth stack is pinned to core 0 -- controller, HCI, BTU, and the
    SBC encode in BTC -- and while streaming it legitimately leaves that core with
    no idle time. The task watchdog reads that as a hung idle task and, every 5 s,
    prints six lines plus a full backtrace over the 115200 UART from a
    high-priority context. That blocking write stalls the audio pipeline long
    enough to starve the I2S DMA, which is audible as a chop on BOTH the local
    speaker and the A2DP stream, once per watchdog period.
    Bench-confirmed by elimination: the chop is identical on 1.0.0, 1.1.0 and
    1.2.0, unaffected by CPU frequency (240 MHz), b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
2026-08-14 hardware(agb): kicad project-file churn (empty STEP export path key)
2026-08-14 firmware(agb): keep the SBC encoder fed at 80 MHz; fix clip playback during A2DP
    The choppy Bluetooth stream was the sink covering for us: the mod delivered
    only ~90% of 44.1 kHz (measured by RTP timestamp advance vs wall clock), so
    the sink ran dry every ~2 s and inserted ~200 ms of silence to re-sync. Core 0
    was the whole story: controller 28% + SBC encode in BTC 43% + BTU 18% + HCI 8%
    left IDLE0 at zero, and BTC, the lowest-priority BT task, ate the shortfall.
    Pinning the CPU at 160 MHz reached 100% delivery, confirming pure CPU
    starvation; the fix keeps 80 MHz instead:
    - Pin the BT controller task to core 1 (CONFIG_BTDM_CTRL_PINNED_TO_CORE_1).
    Core 0 keeps Bluedroid host + encoder and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
    [audio_pipeline.c, console.c]
2026-08-14 firmware(agb): stop the install check flickering warnings
    The web diag card flashed "ADC unavailable" and "HP sense line open" for a
    second at a time. The shared ADC1 unit has four readers (wheel poll, harness
    sampler, battery meter, on-demand diag reads) and adc_oneshot_read fails with
    ESP_ERR_TIMEOUT when another read holds the unit, so an occasional collision
    made a whole oversample burst return -1. The install check reported that as
    VBAT/VOL unknown, and the failed VBAT read also cleared `installed`, which
    reclassified a plugged HP line as "sense line open". Every one-sample flip
    notified the subscribed card.
    Two layers:
    - app_sm: all ADC bursts serialize through a mutex (100 ms timeout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
    [app_sm.c, harness.c]
2026-08-14 firmware(agb): batch spectrum frames into one notify, quiet the streaming link
    The visualizer's notify rate was setting the connected-state click rate. Measured
    on the bench with a 1 kHz square out the HP jack into a line input: clicks arrive
    one per connection event, 15.2/s, peaking ~9 dB below program. At 20 fps every
    connection event carried a frame, so the slave latency granted by
    config_link_quiet never got to skip one.
    Send SPEC_BATCH_DEF frames per notify instead of one. Frames stay fixed-length
    and self-contained so a batch is a plain concatenation, clamped to what the
    negotiated MTU fits; the web app queues them and paces playback at the frame
    interval, so the frame rate is unchang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
    [ble_config.c, console.c]
2026-08-14 web: pace batched spectrum frames back out at the frame rate
    The firmware now packs several spectrum frames into one BLE notify (each notify
    is a radio burst that couples an audible click into the codec, so fewer, bigger
    notifies is the point). Applying a whole batch at once would drop the bars to
    the batch rate, so queue the frames and let the draw loop take one per frame
    interval: same 20 fps, one batch period of lag.
    Frame count comes off the payload length, so this also works against firmware
    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
2026-08-14 firmware(agb): compile at -O2; version 1.3.0
    The whole app was building at the IDF default -Og. Measured during A2DP
    streaming with the BLE spectrum at 20 fps (80 MHz): the audio task averaged 85%
    of its 5.8 ms block budget with 29% of blocks over, and enabling the Bluetooth
    EQ (95% avg) audibly chopped the stream -- float biquads ran at ~37
    cycles/sample despite esp-dsp's optimized assembly, and the plain-C DSP loops
    were worse. The work is CPU-bound (halves at 160 MHz); it was codegen, not
    algorithm.
    With -O2: EQ off 49% avg (1 block over in 12 s), EQ at real gains 56% with
    5/2067 over. EQ + noise reduction + visualizer now fit at 80 MHz with ~44%
    headroom. A2DP delivered rate stays 100%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
2026-08-27 Fix speaker connection instructions in AGB-INSTALL.md
    Corrected instructions for connecting the speaker to the mod PCB.
2026-08-29 docs: add the PCB install and speaker wiring video to the AGB install guide
